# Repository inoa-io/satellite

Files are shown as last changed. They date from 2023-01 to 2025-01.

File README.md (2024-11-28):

# Inoa Satellite



The Inoa Satellite is a lightweight and secure gateway for your fuse box or industrial environment.

Please see our [Project Pages](https://inoa-io.github.io/satellite/) for details.

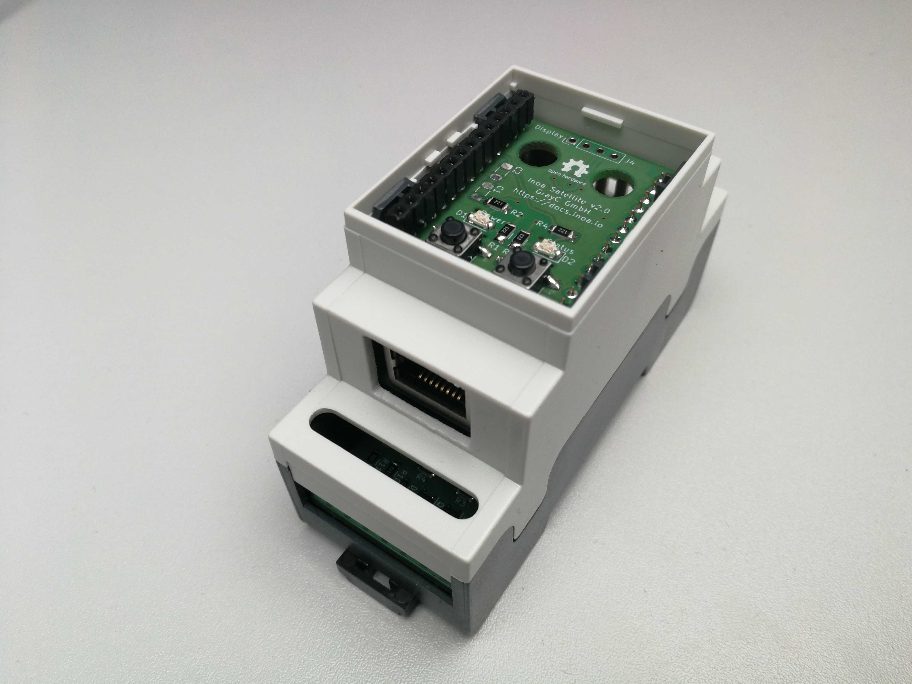
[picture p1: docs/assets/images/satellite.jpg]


## Why?

There is a huge amount of IoT gateways out there, but none of these fulfill completely all of our design goals:

* Usage in a rough industrial environment
* Hardware driven security (HSM)
* Inexpensive hardware to be able to finance a huge fleet of devices
* Low energy consumption
* Fuse box casing (DIN rail)
* Small (2 FE / 36 mm) to allow mounting in existing fuse boxes
* Extendable design to be future proof
* Modular design to adapt hardware to use cases and keep costs low

## How?

We use [KiCad](https://www.kicad.org/) for our PCB designs, [Parts Community](https://b2b.partcommunity.com/) and [SnapEDA](https://www.snapeda.com/) for symbols, footprints, models 'n stuff...

To meet our design goals, we decided to:

* Use the ESP32
* Use the ATECC family of chips as HSM
* Choose industrial proof parts, shielding and ESD protection
* Pick a certified DIN rail casing
* Cut the design to several stacked modules

## Modules

### General

The Satellite comes with a stacked design allowing to interchange the modules on each level of the stack to fit the needs of its planned duty.

This allows quick and cheap adjustment of single devices, ensures expandability, keeps costs low and offers replacement of defect modules with spare parts.

The Satellite consists of up to 4 levels (level 1 is the bottom). Level 3 is an optional level and may be left out.

* Level 1 holds the power supply and metering / control peripheries.
* Level 2 is the main module for the micro controller
* Level 3 is the network / communication level (Ethernet, NB IoT, LoRa, ...)
* Level 4 is meant for the user panel

### Metering Modules

#### Electric Metering Module

The electric metering module is dedicated to be used for interacting with electric meters, inverters, batteries and so on. It is a base module on level 1 of the stack. Its features are:

* 5V-24V power input
* PE / Shield pin
* 2x RS485 interface (used for e.g. ModBus, ...)
* 2x pulse interface (S0, Photoelectric barrier, ...)
* 2x relay driver

#### CT Metering Module

The CT module is dedicated to be used for EMS use cases. Current transformers (split core) with voltage output may be used (e.g. SCT-013).

It is a base module on level 1 of the stack. Its features are:

* 5V-24V power input
* 3x CT
* 1x Analog in (ADC)
* 1x Digital in (e.g. S0 meters)
* 1x RS485 interface (ModBus RTU meters)

#### MBus / WMBus Metering Module

The M-Bus module is dedicated to be used for interacting with different meters via RS485 or M-Bus. The module acts as M-Bus master, but a separate power supply is needed. Because the size of this power supply depends on the amount of connected meters, we decided to give the ability to choose a fitting, external power supply.

The M-Bus module is a base module on level 1 of the stack. Its features are:

* 5V-24V power input
* 1x M-Bus interface
* 1x RS485 interface (ModBus RTU meters)
* 2x pulse interface (S0 meters)
* PE / Shield pins for bus connections

### SoC Module

The SoC module is the heart of the satellite and home of the microprocessor, flash memory and HSM (hardware security module). It is the main module on level 2 of the stack. Its features are:

* ESP32 MPU (32 Bit, Dual Core, 240 MHz)
* 8 MB RAM
* 16 MB flash
* µSD Card slot for external storage
* HSM (ATECC608)

### Ethernet Module

The Ethernet module connects the Satellite to Ethernet. It is a network module on level 3 of the stack. Its features are:

* W5500 Ethernet chip (MAC+PHY)
* ESD protection
* Shielded RJ45 plug

### NB IoT Module

_**Coming soon**_

### LoRa Module

_**Coming soon**_

### Panel Module

The panel module is the "user interface" and home of all user input output devices of the Satellite. It is the top module on level 4. Its features are:

* Power and status LED
* Reset and setup button
* 128x64 OLED display (optional)
* RS232 Debug interface
* External WiFi antenna (optional)

## Casings

We use a DIN rail mounted casing in 2 FE width. See [Datasheet](./casing/rail/apra_rail_Leiterkartengroessen_PCB_Dimensions_de_en.pdf) for details.

## Development

### Building the Project

You will need:

* Python >= 3.8
* [KiBot](https://github.com/INTI-CMNB/KiBot) (see [installation instructions](https://github.com/INTI-CMNB/KiBot#installation-on-ubuntu-or-debian))

Clone this project and run `./build.sh`. You will get a selection of the possible modules to be built. Tests will be executed and the build result is placed in the `out` folder.

### Project structure

| Folder | Purpose |
|---|---|
| ./casing | Construction files for the casing |
| ./configs | KiCad-Export configuration |
| ./development-board  | Design for the development board |
| ./docs | Documentation |
| ./ethernet-extension | Design for the Ethernet module |
| ./libraries | Electric symbols, footprints and 3D models |
| ./metering-module | Design for the metering module |
| ./nbiot-extension | Design for the NB IoT module |
| ./out | Build output folder |
| ./panel-module | Design for the panel module |
| ./soc-module | Design for the SoC module |

### Conventions

#### Markings

* Each PCB has an etched label for "TOP" and "BOT" marks
* Each PCB has an etched label for the product serial following the pattern: SR-XX-NNN (e.g. SR-SM-021)
* The product serial start with "SR" for "Satellite Rail", the next two characters are reserved for the module, the 3 digits represents the version

| Serial | Module / Part | Current Version |
|---|---|---|
| SR-SC-XXX | SoC Module | v2.0 |
| SR-EM-XXX | Electric Metering | v2.0 |
| SR-CM-XXX | Current Loop Metering  | v2.0 |
| SR-MM-XXX | MBus / WMBus Metering  | v2.0 |
| SR-ET-XXX | Ethernet Module | v2.0 |
| SR-NB-XXX | NB IoT Module | v2.0 |
| SR-LR-XXX | LoRa / LoRa WAN Module | v2.0 |
| SR-PN-XXX | Panel Module | v2.0 |

#### Tracks / Vias / Grids

Despite of the low energy consumption of the MCU itself, we are planning with a maximum current of 1A to be future proof for extra extensions that have a higher energy demand (LoRa, NB IoT, ...).

We chose two different of track widths for main power and for data lines (0.25 mm / 0.5 mm) and planned a minimum temperature of 0°C. See the table below.

| Track (mm) | Track (mil) | 10°  | 20°  | 30°  | 40°  | 50°  | 60°  |
|---|---|---|---|---|---|---|---|
| 0.1mm | 4mil | 0.4A | 0.6A | 0.8A | 0.9A | 1.0A | 1.1A |
| 0.2mm | 8mil | 0.7A | 1.0A | 1.2A | 1.4A | 1.6A | 1.7A |
| 0.3mm | 12mil | 0.9A | 1.3A | 1.6A | 1.8A | 2.0A | 2.2A |
| 0.4mm | 16mil | 1.1A | 1.5A | 1.9A | 2.2A | 2.4A | 2.7A |
| 0.5mm | 20mil | 1.3A | 1.8A | 2.2A | 2.5A | 2.8A | 3.1A |
| 0.6mm | 24mil | 1.4A | 2.0A | 2.4A | 2.8A | 3.1A | 3.4A |

We chose a 0.1mm grid for all PCB designs, because our casings and mechanics are also measured in millimeters.

We chose 0.8mm 0.4mm vias.

## Pin Out

| Pin ESP | Pin Satellite | Pin Name  | Standard Purpose |
|---|---|---|---|
| 1 | East 1 | GND | Ground |
| 2 | West 1 | 3V3 | Power supply |
| 3 | West 2 | EN3 | Reset |
| 4 | West 3 | I36 | I2C Interrupt |
| 5 | West 4 | I39 | UART 1 RX |
| 6 | West 5 | I34 | SPI 2 MISO |
| 7 | West 6 | I35 | UART 2 RX |
| 8 | West 7 | IO32 | SPI 2 MOSI |
| 9 | West 8 | IO33 | SPI 2 CLK |
| 10 | West 9 | IO25 | UART 1 TXE |
| 11 | West 10 | IO26 | UART 1 TX |
| 12 | West 11 | IO27 | SPI 2 CS (Ethernet)  |
| 13 | West 12 | IO14 | Ethernet Reset |
| 14 | West 13 | IO12 | |
| 15 | NC | GND | Ground |
| 16 | West 14 | IO13 | Status LED |
| 17 | NC | NC | Internal Flash / RAM |
| 18 | NC | NC | Internal Flash / RAM |
| 19 | NC | NC | Internal Flash / RAM |
| 20 | NC | NC | Internal Flash / RAM |
| 21 | NC | NC | Internal Flash / RAM |
| 22 | NC | NC | Internal Flash / RAM |
| 23 | East 13 | IO15 | UART 2 TX |
| 24 | East 12 | IO2 | UART 2 TXE |
| 25 | East 11 | IO0 | Setup Button |
| 26 | East 10 | IO4 | Ethernet Interrupt |
| 27 | NC | NC | Internal Flash / RAM |
| 28 | NC | NC | Internal Flash / RAM |
| 29 | East 9 | IO5 | SPI 1 CS (SD) |
| 30 | East 8 | IO18 | SPI 1 CLK |
| 31 | East 7 | IO19 | SPI 1 MISO |
| 32 | NC | NC | Internal Flash / RAM |
| 33 | East 6 | IO21 | I2C SDA |
| 34 | East 5 | URXD0 | UART 0 RX |
| 35 | East 4 | UTXD0 | UART 0 TX |
| 36 | East 3 | IO22 | I2C SCL |
| 37 | East 2 | IO23 | SPI 1 MOSI |
| 38 | East 1 | GND | Ground |
| NC | East 14 | Shield | Shield / PE |

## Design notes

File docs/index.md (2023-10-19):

# Inoa Satellite Gateway

Satellite Gateway

## General

The Inoa Satellite is a lightweight and secure gateway for your fuse box or industrial environment with a DIN rail mounted casing which is 2 FE wide.

It features an ESP32 MPU with 240MHz dual core, 8MB Ram, 16MB program flash and a SD card slot for SSD usage.

## Design Goals

* Usage in a rough industrial environment
* Hardware driven security (HSM)
* Cheap hardware to be able to finance a huge fleet of devices
* Low energy consumption due to possible battery driven usage
* Fuse box casing (DIN rail)
* Small (2 FE / 36mm) to allow mounting in existing fuse boxes
* Extendable design to be future proof
* Modular design to adapt hardware to use cases and keep costs low

## Modular Design

The Satellite comes with a stacked design allowing to interchange the modules on each level of the stack to fit the needs of its planned duty.

This allows quick and cheap adjustment of single devices, ensures expandability, keeps costs low and offers replacement of defect modules with spare parts.

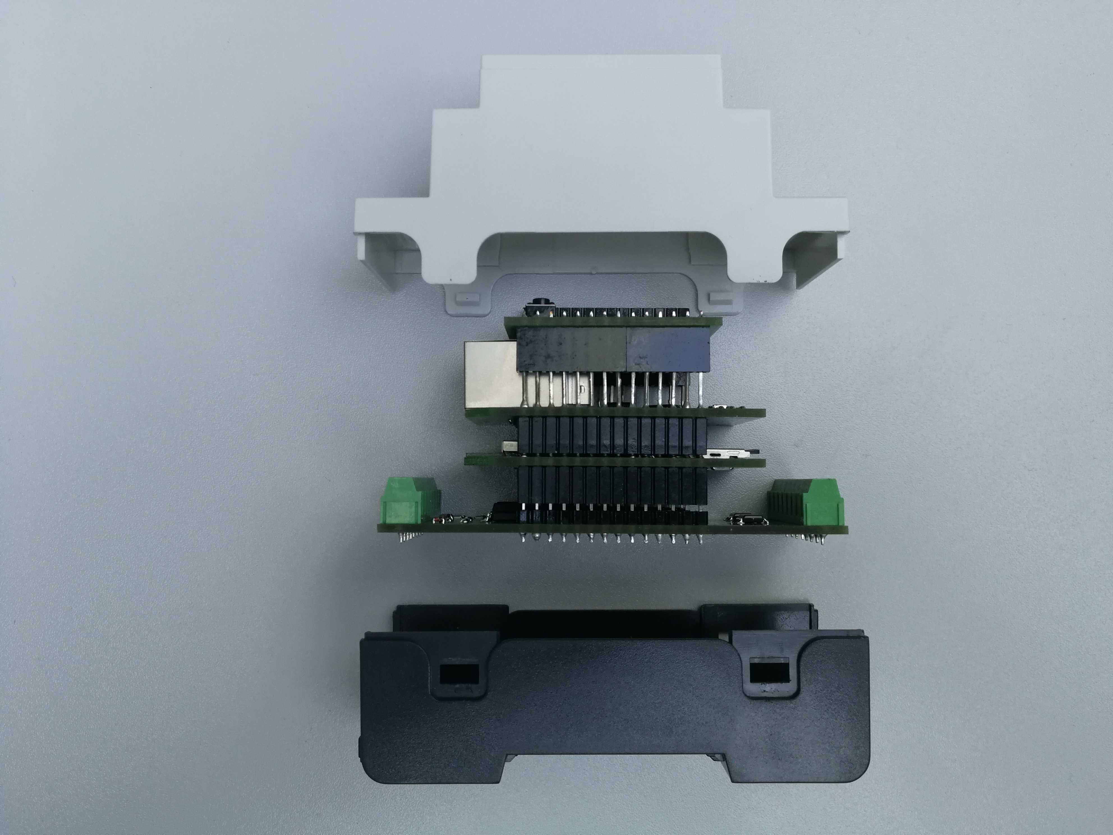
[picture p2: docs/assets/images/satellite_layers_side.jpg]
Satellite Module Layers


The Satellite consists of up to 4 levels (level 1 is the bottom). Level 3 is an optional level and may be left out.

* Level 1 holds the power supply and metering / control peripheries.
* Level 2 is the main module for the micro controller
* Level 3 is the network / communication level (Ethernet, NB IoT, LoRa, ...)
* Level 4 is meant for the user panel or other external I/O interfaces

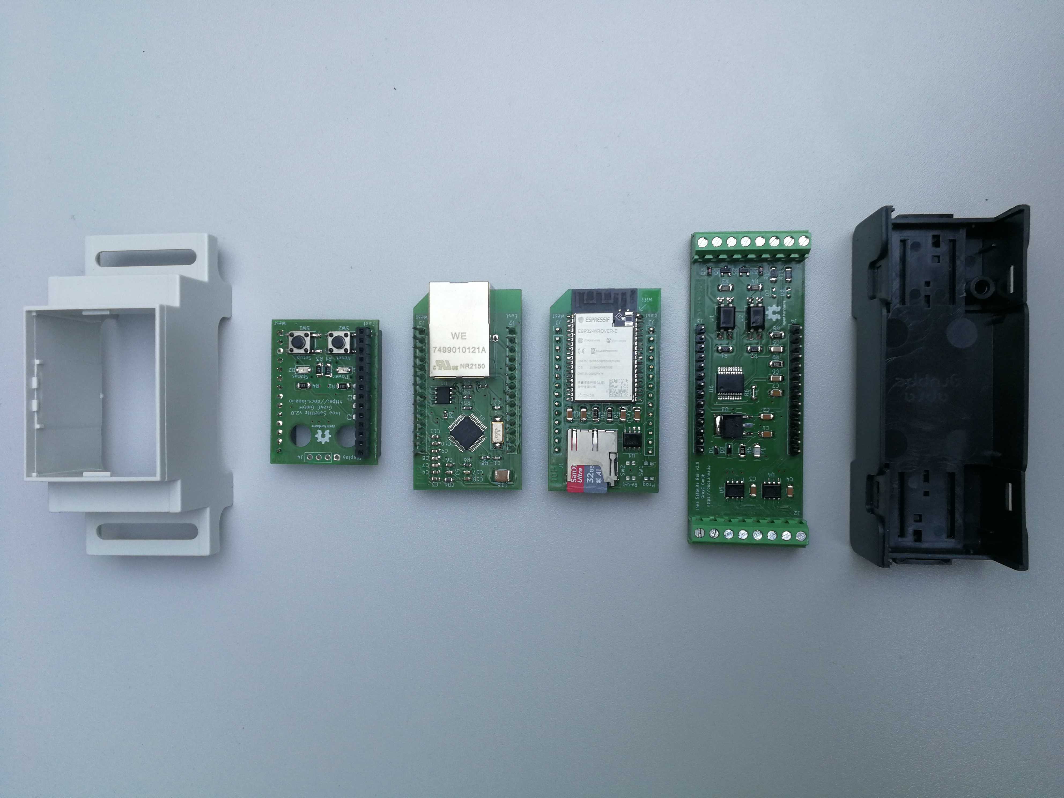
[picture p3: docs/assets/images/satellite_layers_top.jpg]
Satellite Module Layers


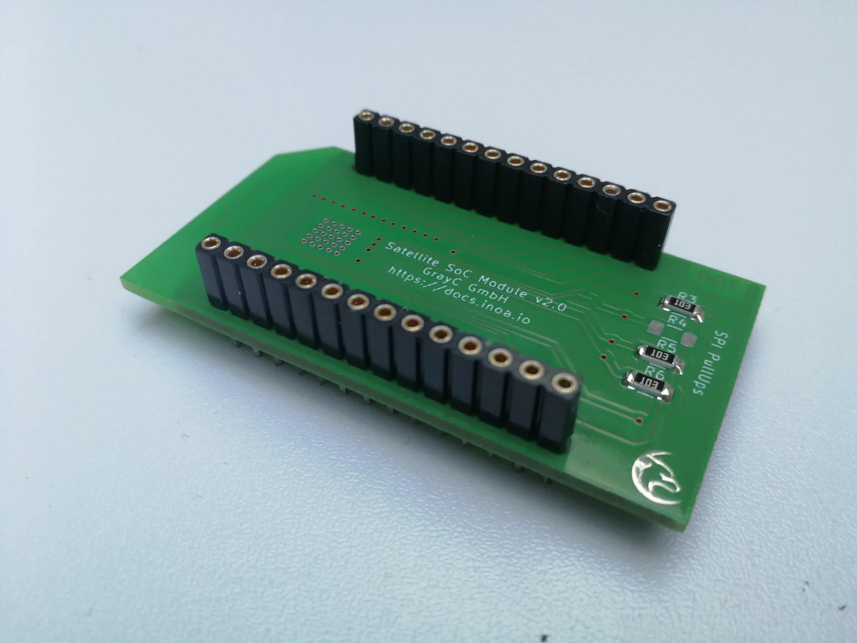
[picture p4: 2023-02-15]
docs/assets/images/satellite_soc_bottom.jpg

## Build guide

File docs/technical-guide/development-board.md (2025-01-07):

# Development Board

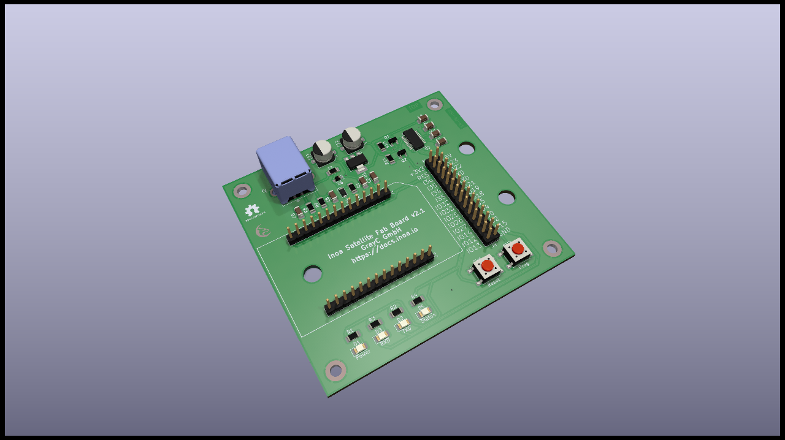
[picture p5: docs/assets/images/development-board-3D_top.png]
Development Board Model


## Specifications

The Development Board is a tool to flash, debug and develop new Satellite modules. Any Satellite module can be connected to the board. Even a whole stack (SoC, networtk and panel module) can be used. The module has an USB connection that will power the connected modules when plugged in. Also, the module has an onboard USB to UART adapter, so the Satellites' debug console can be used directly via USB. The board has an auto programmer circuit, so connected SoC modules can be automatically flashed from the host PC. For further development, there is also a pin header providing the complete system bus.

## Schematics

Development Board Schematics

## Resources

* [PCB Top](../generated/pcb/development-board-F_Cu.svg)
* [PCB Bottom](../generated/pcb/development-board-B_Cu.svg)
* [Bill of material](../generated/bom/development-board-bom.csv)

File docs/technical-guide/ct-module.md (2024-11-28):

# CT Module

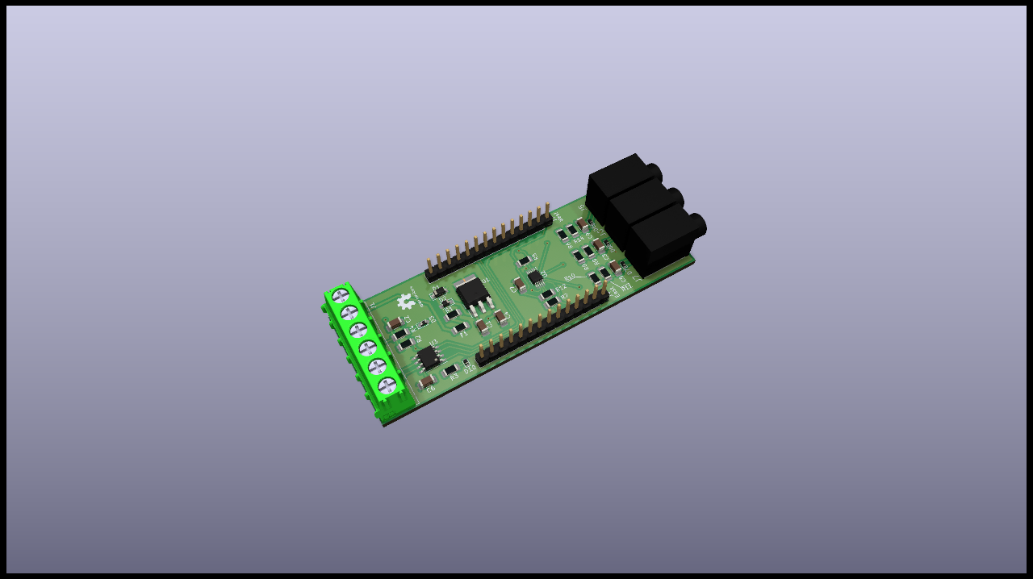
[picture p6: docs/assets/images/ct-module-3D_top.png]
CT Module Model


## Specifications

The CT module is dedicated to be used for EMS use cases. Current transformers (split core) with voltage output may be used (e.g. SCT-013).

It is a base module on level 1 of the stack. Its features are:

* 5V-24V power input
* 3x CT
* 1x Analog in (ADC)
* 1x Digital in (e.g. S0 meters)
* 1x RS485 interface (ModBus RTU meters)

## Schematics

CT Module Schematics

## Resources

* [PCB Top](../generated/pcb/ct-module-F_Cu.svg)
* [PCB Bottom](../generated/pcb/ct-module-B_Cu.svg)
* [Bill of material](../generated/bom/ct-module-bom.csv)

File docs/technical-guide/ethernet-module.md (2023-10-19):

# Ethernet Module

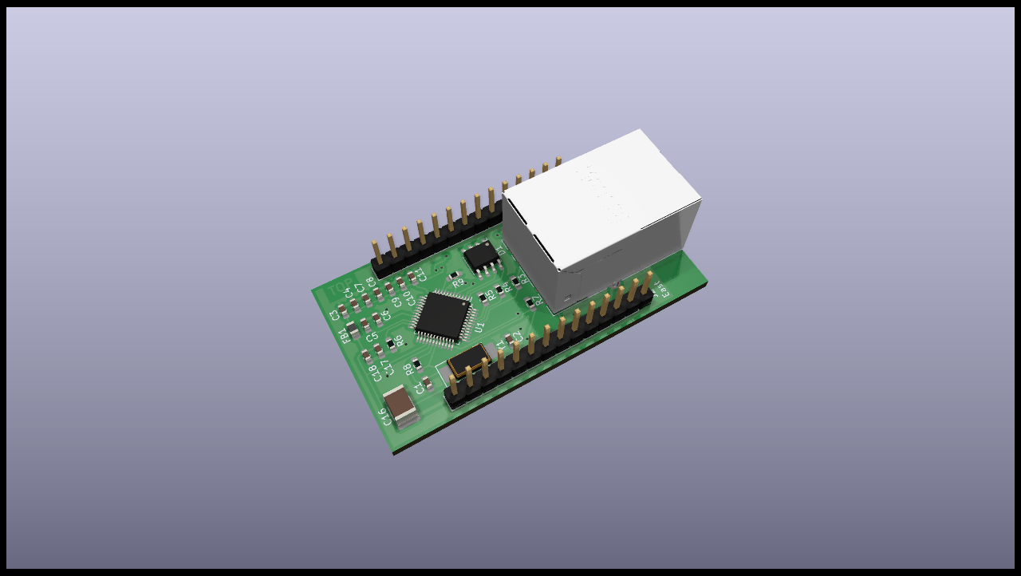
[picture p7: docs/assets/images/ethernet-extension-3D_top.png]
Ethernet Module Model


## Specifications

The Ethernet module connects the Satellite to Ethernet. It is a network module on level 3 of the stack. Its features are:

* W5500 Ethernet chip (MAC+PHY)
* ESD protection
* Shielded RJ45 plug

## Schematics

Ethernet Module Schematics

## Resources

* [PCB Top](../generated/pcb/ethernet-extension-F_Cu.svg)
* [PCB Bottom](../generated/pcb/ethernet-extension-B_Cu.svg)
* [Bill of material](../generated/bom/ethernet-extension-bom.csv)

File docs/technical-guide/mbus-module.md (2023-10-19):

# M-Bus Module

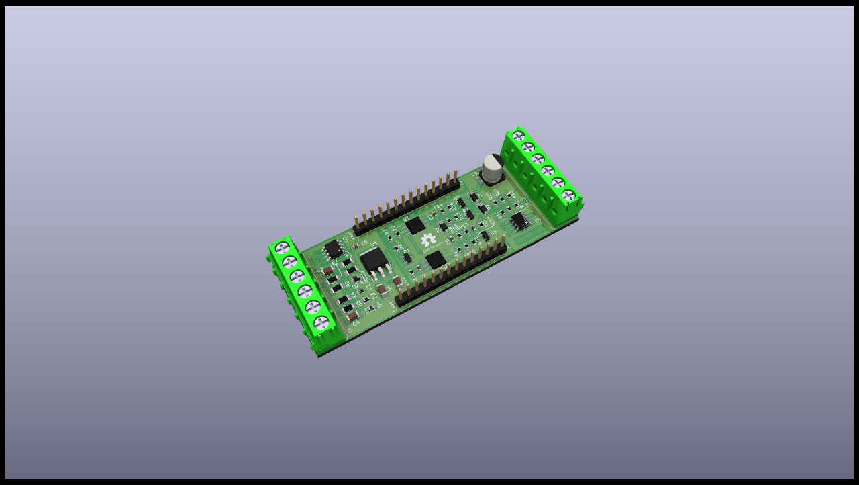
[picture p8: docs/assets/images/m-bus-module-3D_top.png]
M-Bus Module Model


## Specifications

The M-Bus module is dedicated to be used for interacting with different meters via RS485 or M-Bus. The module acts as M-Bus master, but a separate power supply is needed. Because the size of this power supply depends on the amount of connected meters, we decided to give the ability to choose a fitting, external power supply.

The M-Bus module is a base module on level 1 of the stack. Its features are:

* 5V-24V power input
* 1x M-Bus interface
* 1x RS485 interface (ModBus RTU meters)
* 2x pulse interface (S0 meters)
* PE / Shield pins for bus connections

## Schematics

M-Bus Module Schematics

## Resources

* [PCB Top](../generated/pcb/m-bus-module-F_Cu.svg)
* [PCB Bottom](../generated/pcb/m-bus-module-B_Cu.svg)
* [Bill of material](../generated/bom/m-bus-module-bom.csv)

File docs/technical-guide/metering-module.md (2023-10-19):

# Electric Metering Module

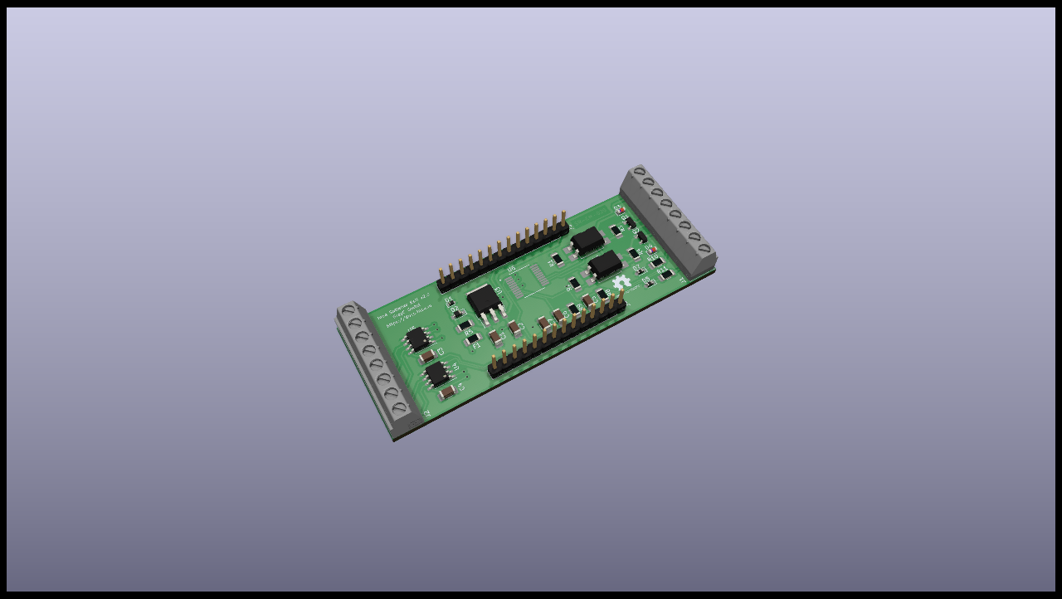
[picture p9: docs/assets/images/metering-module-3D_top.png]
Electric Metering Module Model


## Specifications

The electric metering module is dedicated to be used for interacting with electric meters, inverters, batteries and so on. It is a base module on level 1 of the stack. Its features are:

* 5V-24V power input
* PE / Shield pin
* 2x RS485 interface (used for e.g. ModBus, ...)
* 2x pulse interface (S0, Photoelectric barrier, ...)
* 2x relay driver

## Schematics

Electric Metering Module Schematics

## Resources

* [PCB Top](../generated/pcb/metering-module-F_Cu.svg)
* [PCB Bottom](../generated/pcb/metering-module-B_Cu.svg)
* [Bill of material](../generated/bom/metering-module-bom.csv)

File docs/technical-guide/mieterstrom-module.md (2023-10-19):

# Mieterstrom Module

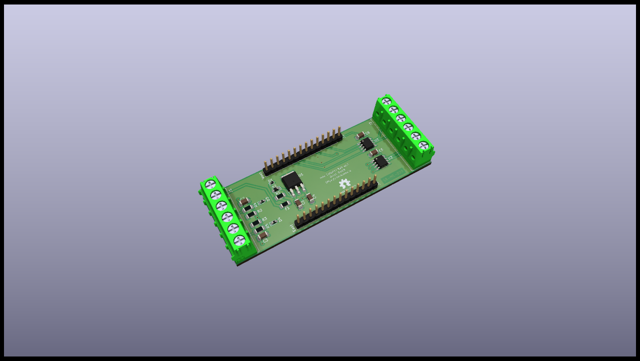
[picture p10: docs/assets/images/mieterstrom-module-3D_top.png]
Mieterstrom Module Model


## Specifications

The Mieterstrom module is dedicated to be used for interacting with electric meters in a tenement environment. In this case, there are different types of meters used and so a need of different bus speeds may needed.

It is a base module on level 1 of the stack. Its features are:

* 5V-24V power input
* 2x RS485 interface (ModBus RTU meters)
* 2x pulse interface (S0 meters)
* PE / Shield pins for bus connections

## Schematics

Mieterstrom Module Schematics

## Resources

* [PCB Top](../generated/pcb/mieterstrom-module-F_Cu.svg)
* [PCB Bottom](../generated/pcb/mieterstrom-module-B_Cu.svg)
* [Bill of material](../generated/bom/mieterstrom-module-bom.csv)

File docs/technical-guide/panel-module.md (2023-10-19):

# Panel Module

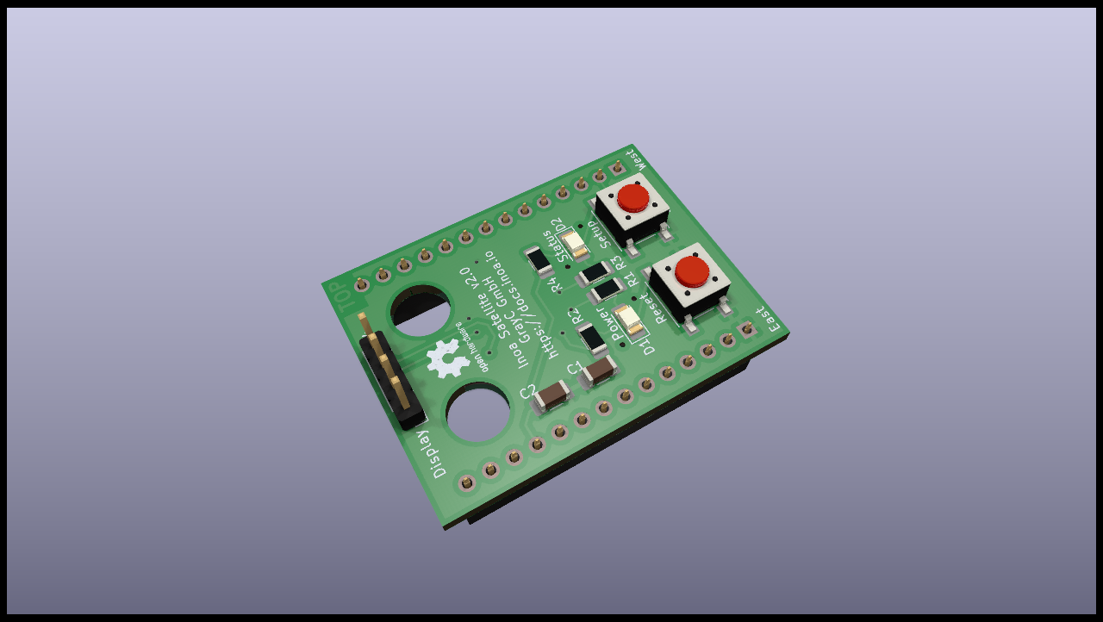
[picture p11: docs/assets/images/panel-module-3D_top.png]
Panel Module Model


## Specifications

The panel module is the "User Interface" and home of all user input output devices of the Satellite. It is the top module on level 4. Its features are:

* Power and status LED
* Reset and setup button
* 128x64 OLED display (optional)
* RS232 Debug interface
* External WiFi antenna (optional)

## Schematics

Panel Module Schematics

## Resources

* [PCB Top](../generated/pcb/panel-module-F_Cu.svg)
* [PCB Bottom](../generated/pcb/panel-module-B_Cu.svg)
* [Bill of material](../generated/bom/panel-module-bom.csv)

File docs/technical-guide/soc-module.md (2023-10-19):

# SoC Module

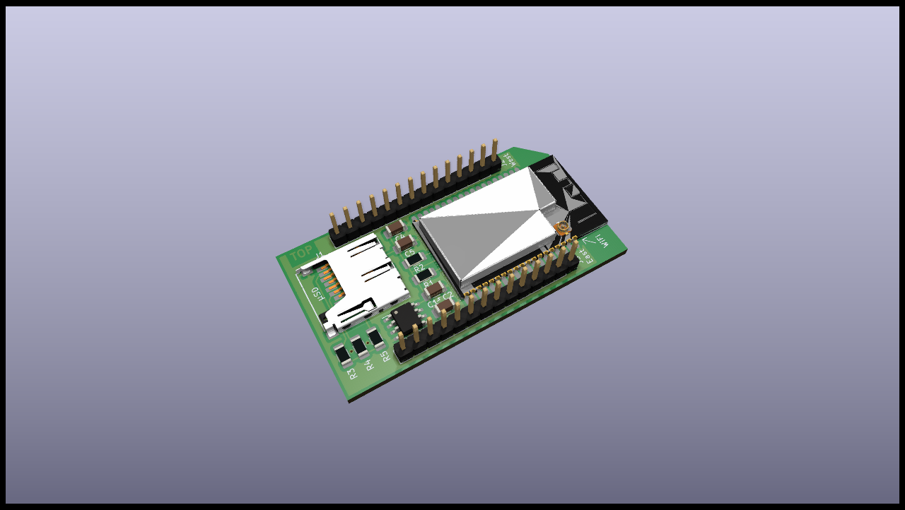
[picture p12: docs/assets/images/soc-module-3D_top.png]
Test


## Specifications

The SoC module is the heart of the Satellite and home of the microprocessor, flash memory and HSM (hardware security module). It is the main module on level 2 of the stack. Its features are:

* ESP32 MPU (32 Bit, Dual Core, 240 MHz)
* 8 MB RAM
* 16 MB flash
* µSD Card slot for external storage
* HSM (ATECC608)
* RTC (DS3231)

## Schematics

SoC Module Schematics

## Resources

* [PCB Top](../generated/pcb/soc-module-F_Cu.svg)
* [PCB Bottom](../generated/pcb/soc-module-B_Cu.svg)
* [Bill of material](../generated/bom/soc-module-bom.csv)

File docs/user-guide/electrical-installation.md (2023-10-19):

# Electrical Installation

The electrical installation may differ based on the metering module of the satellite. Some modules might have other pin connection based on the provided interfaces (e.g. ModBus, CAN, KNX, ...).

Please find the installation instructions for your specific model below.

## General

All Satellite "Rail" models are meant to be mounted on a DIN rail at indoor sites. For outdoor usage please refer to the Satellite "Probe" models.

All models uses internal micro SD cards as file storage. You can insert an SD card of your choice by opening the case popping the 4 latches out with a screw driver. The card can be inserted at the upper side of the PCB "sandwich".

## Tenant Electricity Model

The metering model is able to connect to 2 different RS485 buses (e.g. ModBus) running on different baud rates. It is also fitted with 2 digital inputs (e.g. S0).

Please find to pin out below:

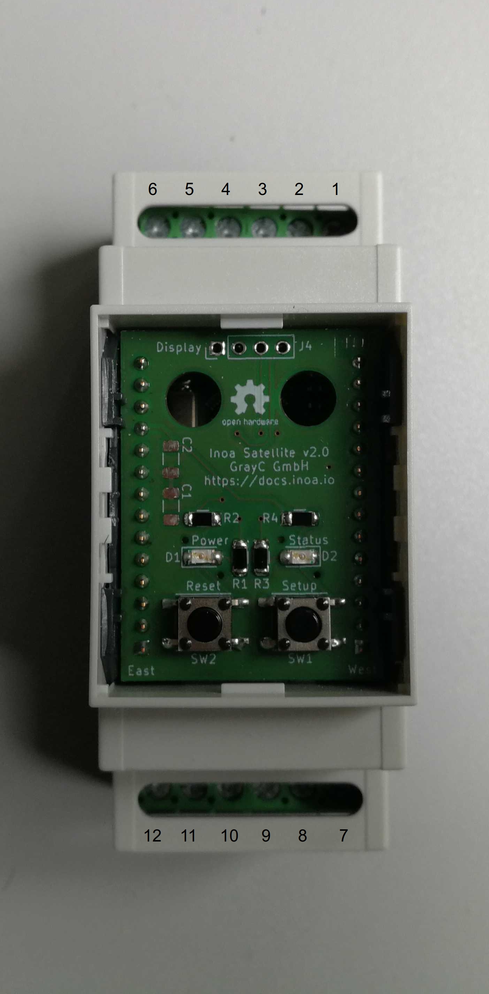
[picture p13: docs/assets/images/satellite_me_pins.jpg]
Satellite Gateway Pins


| Pin | Purpose | Description |
|-----|---|---|
| 1 | +5-24V | Power supply positive 5 to 24 volts, >=3W |
| 2 | Ground | Power supply ground |
| 3 | S0 1 + | S0 interface |
| 4 | S0 1 - | S0 interface |
| 5 | S0 2 + | S0 interface |
| 6 | S0 2 - | S0 interface |
| 7 | RS485 1-B | RS485 1 "B" line |
| 8 | RS485 1-A | RS485 1 "A" line |
| 9 | RS485 1-GND | RS485 1 Ground line (shield) |
| 10  | RS485 2-B | RS485 2 "B" line |
| 11  | RS485 2-A | RS485 2 "A" line |
| 12  | RS485 2-GND | RS485 2 Ground line (shield) |

Connect Pin 1 and 2 to a power supply delivering 5 to 24 volts. Be aware that the best efficiency is achieved with 5 volts. Higher voltages will lead to higher thermal loss. The power supply must be rated for at least 3W.

Connect the RS485 pins as described in the table. Be sure to connect the shield of the RS485 buses to ground pin to avoid stability problems. The Satellite does **not** have internal termination resistors!

The S0 pins should be connected to a S0 device, reed contact, incremental wind sensor, and any other device that uses a simple switch inside.

## M-Bus Model

The M-Bus model is able to connect to a RS485 bus (e.g. ModBus) and also acts as M-Bus master. It is also fitted with 2 digital inputs (e.g. S0).

Please find to pin out below:

Satellite Gateway Pins

| Pin | Purpose | Description |
|-----|---|---|
| 1 | +5-24V | Power supply positive 5 to 24 volts, >=3W |
| 2 | Ground | Power supply ground |
| 3 | S0 1 + | S0 interface |
| 4 | S0 1 - | S0 interface |
| 5 | S0 2 + | S0 interface |
| 6 | S0 2 - | S0 interface |
| 7 | RS485 1-B | RS485 1 "B" line |
| 8 | RS485 1-A | RS485 1 "A" line |
| 9 | M-Bus M- | M-Bus negative bus line |
| 10  | M-Bus M+ | M-Bus positive bus line |
| 11  | M-Bus DC- | M-Bus power supply 9-30V (-) |
| 12  | M-Bus DC+ | M-Bus power supply 9-30V (+) |

Connect Pin 1 and 2 to a power supply delivering 5 to 24 volts. Be aware that the best efficiency is achieved with 5 volts. Higher voltages will lead to higher thermal loss. The power supply must be rated for at least 3W.

Connect the RS485 pins as described in the table. Be sure to connect the shield of the RS485 bus to ground pin to avoid stability problems. The Satellite does **not** have internal termination resistors!

The S0 pins should be connected to a S0 device, reed contact, incremental wind sensor, and any other device that uses a simple switch inside.

Pin 9 and 10 acts as M-Bus data line. Connect the M-Bus power supply to pin 11 and 12. Be sure to use the correct polarity! The power supply drives the M-Bus, so choose a fitting one depending on the number of connected meters.

## Electric Metering Model

The metering model is able to connect to 2 different RS485 buses (e.g. ModBus) running on different baud rates. It is also able to drive 2 relays and to connect to 2 digital inputs (e.g. S0).

Please find to pin out below:

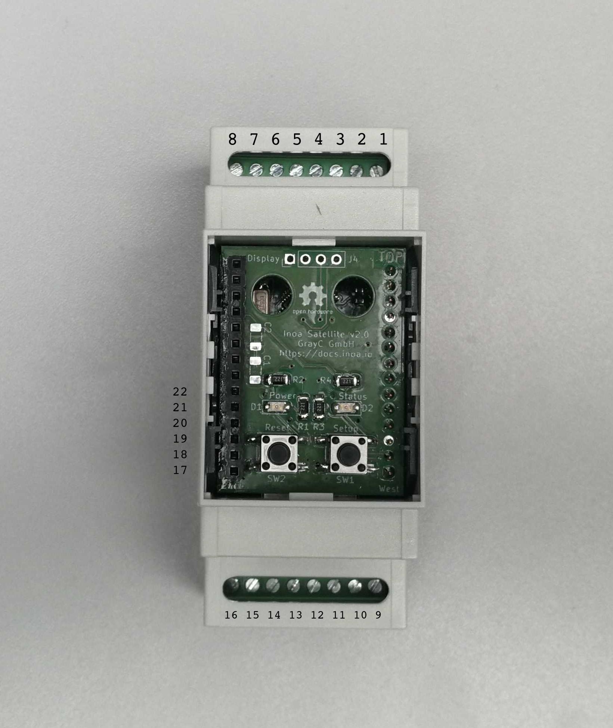
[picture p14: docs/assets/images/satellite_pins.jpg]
Satellite Gateway Pins


| Pin | Purpose | Description |
|-----|---|---|
| 1 | +5-24V | Power supply positive 5 to 24 volts |
| 2 | Ground | Power supply ground |
| 3 | Shield | Connect to earth |
| 4 | shield | Connect to earth |
| 5 | RS485 1-A | RS485 "A" line |
| 6 | RS485 1-B | RS485 "B" line |
| 7 | RS485 2-A | RS485 "A" line |
| 8 | RS485 2-B | RS485 "B" line |
| 9 | Relay Power + | Power supply for relays positive (e.g. 12 or 24 volts) |
| 10  | Relay Power - | Power supply for relays ground |
| 11  | Relay 1 | Relay switch (will become negative if switched) |
| 12  | Relay 2 | Relay switch (will become negative if switched) |
| 13  | S0 1 + | S0 interface |
| 14  | S0 1 - | S0 interface |
| 15  | S0 2 + | S0 interface |
| 16  | S0 2 - | S0 interface |
| 17  | Ground | Power supply ground |
| 18  | Do not use | Do not use (future use for internal SD) |
| 19  | I²C SCL | External I²C |
| 20  | Debug UART TX | Debug console |
| 21  | Debug UART RX | Debug console |
| 22  | I²C SDA | External I²C |
| >22 | Do not use | Do not use (future use for internal SD) |

Connect Pin 1 and 2 to a power supply delivering 5 to 24 volts. Be aware that the best efficiency is achieved with 5 volts. Higher voltages will lead to higher thermal loss. The power supply must be rated for at least 3W.

Connect the RS485 pins as described in the table. Be sure to connect the shield of the RS485 bus to pin 3 or 4 to avoid stability problems. The Satellite does **not** have internal termination resistors!

The S0 pins should be connected to a S0 device, reed contact, incremental wind sensor, and any other device that uses a simple switch inside.

The relay power contacts have to be connected to an external power source. You might use the same power supply as used for the Satellite itself - depending on the voltage ratings of the used relay. Connect one positive wire of the power supply to your relay positive input. The negative input of the relay is connected to one of the switch pins 11 or 12.

## Debug console

All Satellite models can be debugged using an USB to UART adapter like the FT232. Connect the adapter to your PC. Connect the TX line to pin 20 and the RX line to pin 21. You also have to connect the ground line to pin 17.

Use a terminal tool of your choice, e.g. [GTKTerm](https://github.com/Jeija/gtkterm). Set the baud rate to 115200 and the bit configuration to 8N1.

Please refer to the developer guide for further information about dealing with the debug console!

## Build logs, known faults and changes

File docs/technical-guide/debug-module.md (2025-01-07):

# Debug Module

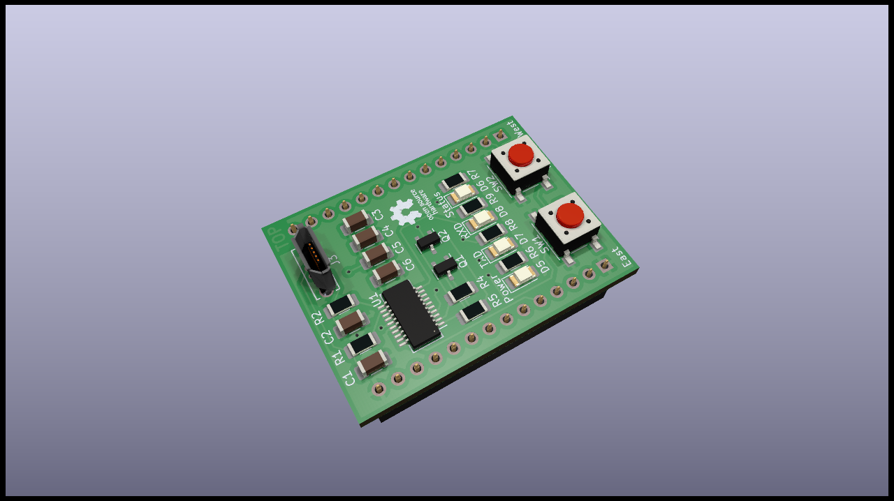
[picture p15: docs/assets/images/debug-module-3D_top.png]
Debug Module Model


## Specifications

The Debug module is a tool to debug Satellites at its installation place. The panel module is removed and the debug module is put at its place instead. The module has an USB connection that will power the Satellite when plugged in. Also, the module has an onboard USB to UART adapter, so the Satellites' debug console can be used directly via USB.

## Schematics

Debug Module Schematics

## Resources

* [PCB Top](../generated/pcb/debug-module-F_Cu.svg)
* [PCB Bottom](../generated/pcb/debug-module-B_Cu.svg)
* [Bill of material](../generated/bom/debug-module-bom.csv)

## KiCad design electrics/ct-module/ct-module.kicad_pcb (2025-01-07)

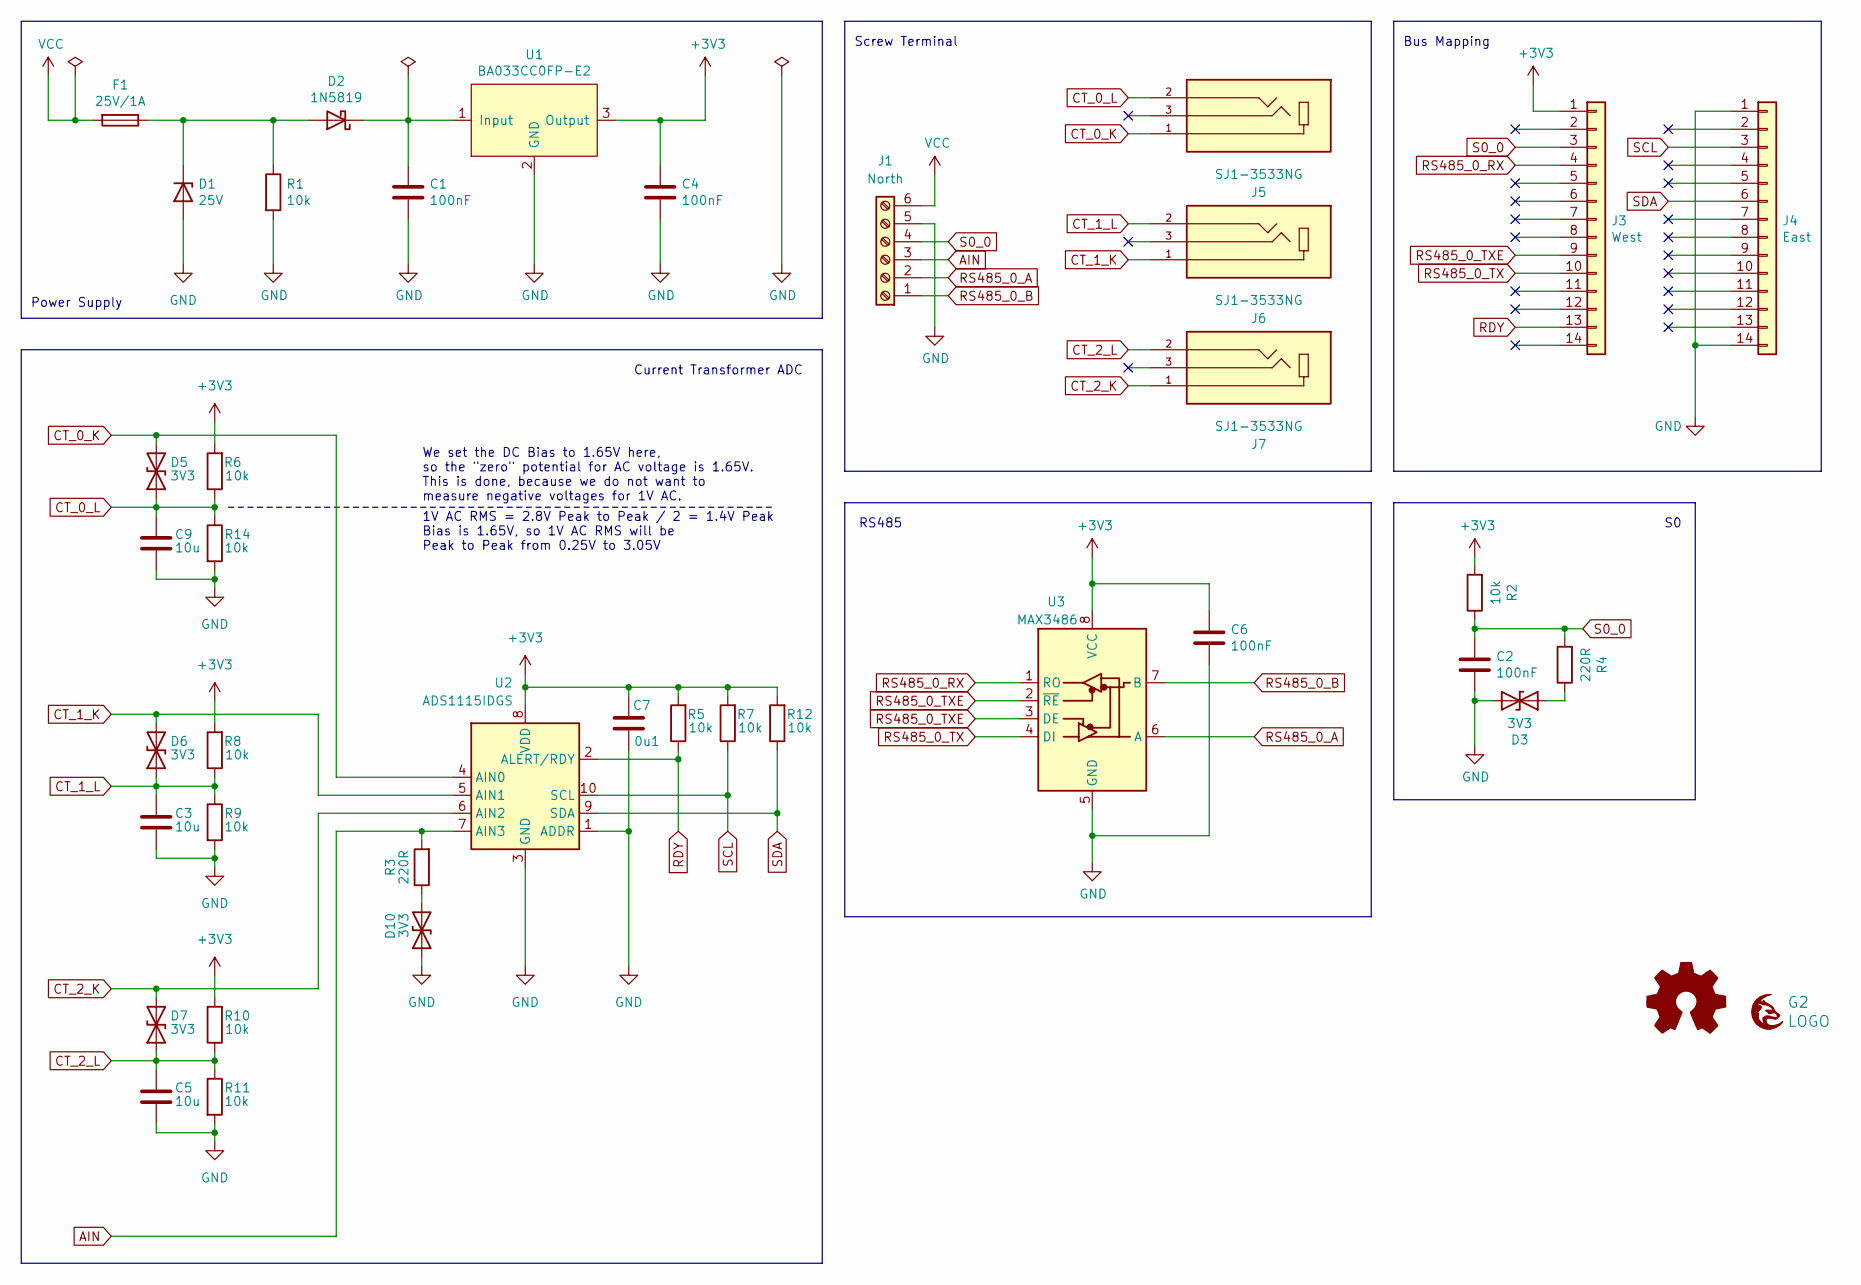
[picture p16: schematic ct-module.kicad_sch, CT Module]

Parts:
C1, C2, C4, C6: 100nF; C_1206_3216Metric_Pad1.33x1.80mm_HandSolder; mouser# 80-C1206C104M5R
C3, C5, C9: 10u; C_1206_3216Metric_Pad1.33x1.80mm_HandSolder; mouser# 80-C1206C106M9R
C7: 0u1; C_1206_3216Metric_Pad1.33x1.80mm_HandSolder; mouser# 80-C1206C104M5R
D1: 25V; D_SOD-123; mouser# 78-MMSZ5253C-E3-08
D2: 1N5819; D_SOD-323_HandSoldering; mouser# 771-PMEG4010CEAX
D3, D5, D6, D7, D10: 3V3; D_0603_1608Metric_Pad1.05x0.95mm_HandSolder; mouser# 652-CG0603MLC-3.3LE
F1: 25V/1A; Fuse_1206_3216Metric_Pad1.42x1.75mm_HandSolder; mouser# 504-TR/3216FF1-R
G1: Logo_Open_Hardware_Small; OSHW-Logo2_7.3x6mm_SilkScreen
G2: LOGO; grayc-logo-negative
J1: North; PHOENIX_1935200; mouser# 651-1935200
J3: West; PinHeader_1x14_P2.54mm_Vertical; mouser# 855-M20-9991446
J4: East; PinHeader_1x14_P2.54mm_Vertical; mouser# 855-M20-9991446
J5, J6, J7: SJ1-3533NG; CUI_SJ1-3533NG; mouser# 490-SJ1-3533NG
R1, R2, R5, R6, R7, R8, R9, R10, R11, R12, R14: 10k; R_1206_3216Metric_Pad1.30x1.75mm_HandSolder; mouser# 652-CR1206JW-103ELF
R3, R4: 220R; R_1206_3216Metric_Pad1.30x1.75mm_HandSolder; mouser# 652-CR0603FX-2200ELF
U1: BA033CC0FP-E2; TO-252-3_TabPin2; mouser# 755-BA033CC0FP-E2
U2: ADS1115IDGS; VSSOP-10_3x3mm_P0.5mm
U3: MAX3486; SOIC-8_3.9x4.9mm_P1.27mm; mouser# 700-MAX3486EESA

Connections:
+3V3: C4.1, C6.1, C7.2, J3.1, R2.2, R5.2, R6.2, R7.2, R8.2, R10.2, R12.2, U1.3 (Output), U2.8 (VDD), U3.8 (VCC)
AIN: J1.3, R3.2, U2.7 (AIN3)
CT_0_K: D5.2 (A2), J5.1, U2.4 (AIN0)
CT_0_L: C9.1, D5.1 (A1), J5.2, R6.1, R14.1
CT_1_K: D6.2 (A2), J6.1, U2.5 (AIN1)
CT_1_L: C3.1, D6.1 (A1), J6.2, R8.1, R9.1
CT_2_K: D7.2 (A2), J7.1, U2.6 (AIN2)
CT_2_L: C5.1, D7.1 (A1), J7.2, R10.1, R11.1
GND: C1.2, C2.2, C3.2, C4.2, C5.2, C6.2, C7.1, C9.2, D1.2 (A), D3.2 (A2), D10.1 (A1), J1.5, J4.1, J4.14, R1.2, R9.2, R11.2, R14.2, U1.2 (GND), U2.1 (ADDR), U2.3 (GND), U3.5 (GND)
unnamed: C1.1, D2.1 (K), U1.1 (Input)
unnamed: D1.1 (K), D2.2 (A), F1.1, R1.1
unnamed: D3.1 (A1), R4.1
unnamed: D10.2 (A2), R3.1
RDY: J3.13, R5.1, U2.2 (ALERT/RDY)
RS485_0_A: J1.2, U3.6 (A)
RS485_0_B: J1.1, U3.7 (B)
RS485_0_RX: J3.4, U3.1 (RO)
RS485_0_TX: J3.10, U3.4 (DI)
RS485_0_TXE: J3.9, U3.2 (~RE), U3.3 (DE)
S0_0: C2.1, J1.4, J3.3, R2.1, R4.2
SCL: J4.3, R7.1, U2.10 (SCL)
SDA: J4.6, R12.1, U2.9 (SDA)
VCC: F1.2, J1.6

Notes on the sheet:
Bus Mapping
1V AC RMS = 2.8V Peak to Peak / 2 = 1.4V Peak Bias is 1.65V, so 1V AC RMS will be Peak to Peak from 0.25V to 3.05V
We set the DC Bias to 1.65V here, so the "zero" potential for AC voltage is 1.65V. This is done, because we do not want to measure negative voltages for 1V AC.
Current Transformer ADC
RS485
Power Supply
Screw Terminal

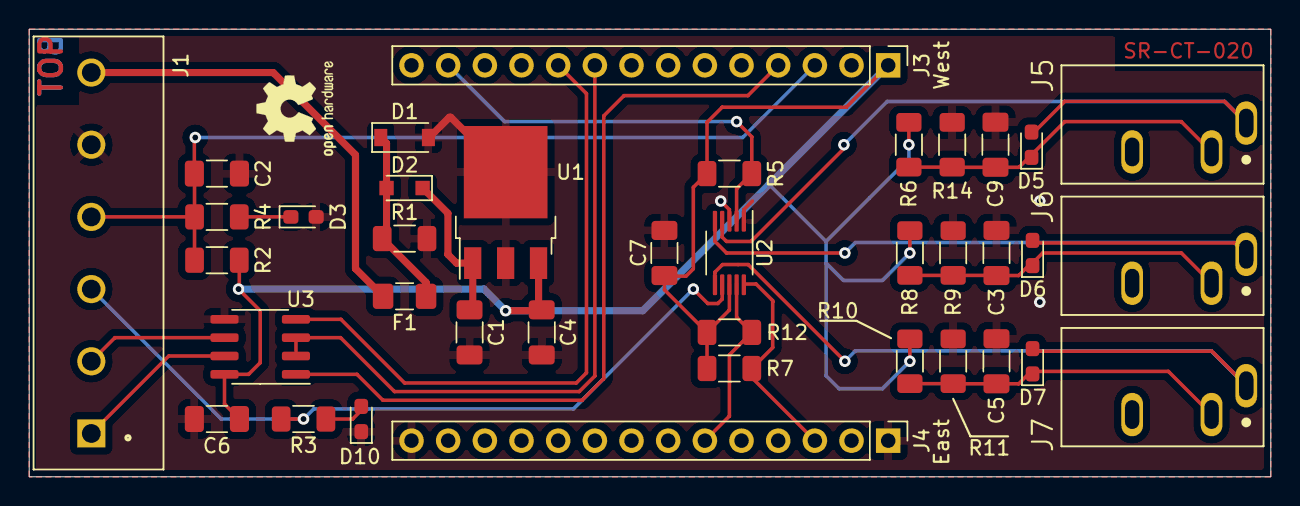
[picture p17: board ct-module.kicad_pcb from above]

Board: 2 copper layers, 86.0 x 31.0 mm, 40 parts (1 on the bottom side), 23 nets.

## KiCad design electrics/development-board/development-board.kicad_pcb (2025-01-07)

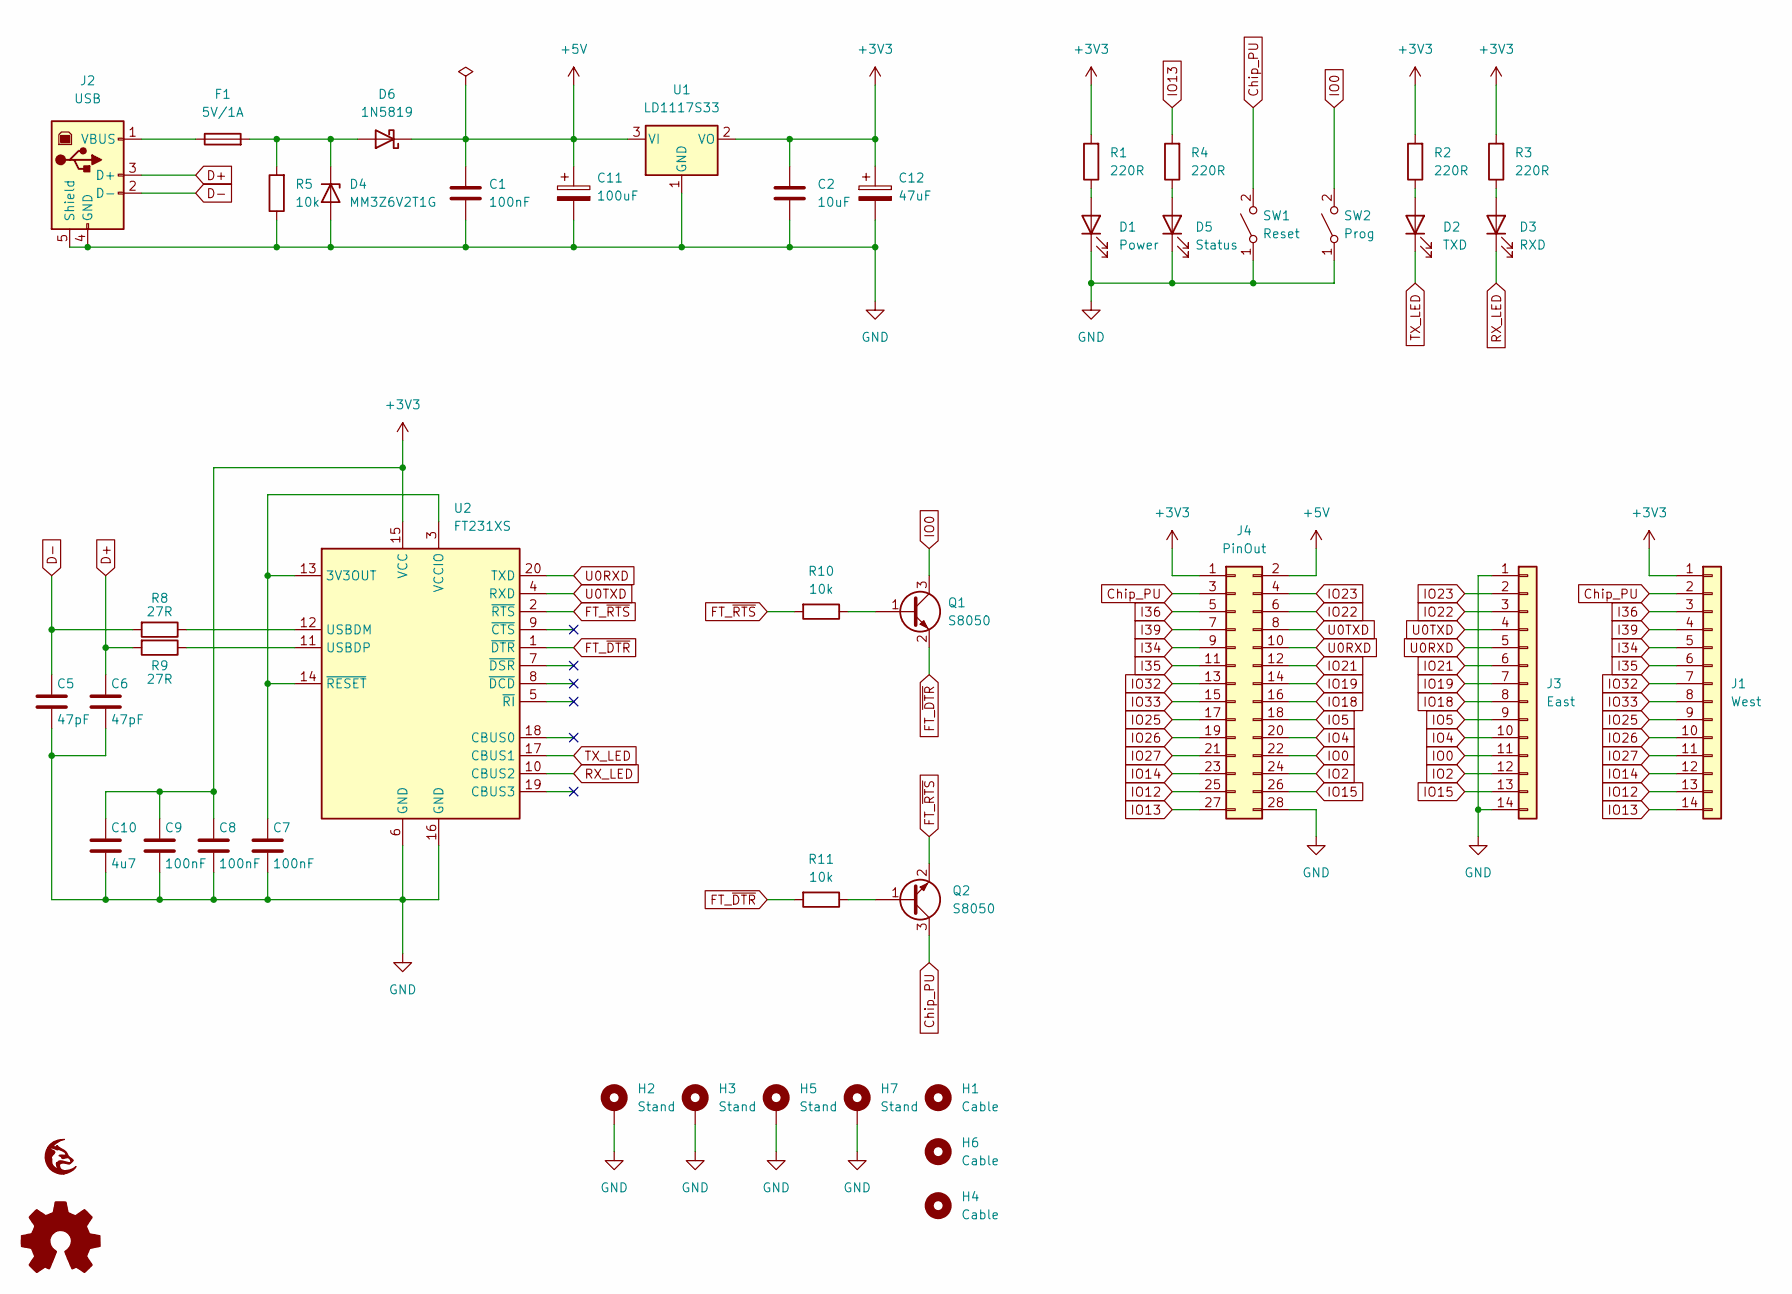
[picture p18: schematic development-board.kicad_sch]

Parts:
C1, C7, C8, C9: 100nF; C_1206_3216Metric_Pad1.33x1.80mm_HandSolder
C2: 10uF; C_1206_3216Metric_Pad1.33x1.80mm_HandSolder
C5, C6: 47pF; C_1206_3216Metric_Pad1.33x1.80mm_HandSolder
C10: 4u7; C_1206_3216Metric_Pad1.33x1.80mm_HandSolder
C11: 100uF; CP_Elec_6.3x5.4
C12: 47uF; CP_Elec_6.3x5.4
D1: Power; LED_1206_3216Metric_Pad1.42x1.75mm_HandSolder
D2: TXD; LED_1206_3216Metric_Pad1.42x1.75mm_HandSolder
D3: RXD; LED_1206_3216Metric_Pad1.42x1.75mm_HandSolder
D4: MM3Z6V2T1G; D_SOD-123F
D5: Status; LED_1206_3216Metric_Pad1.42x1.75mm_HandSolder
D6: 1N5819; D_SOD-323_HandSoldering
F1: 5V/1A; Fuse_1206_3216Metric_Pad1.42x1.75mm_HandSolder
G1: LOGO; grayc-logo-negative
H1, H4, H6: Cable; MountingHole_5.5mm
H2, H3, H5, H7: Stand; MountingHole_3.2mm_M3_DIN965_Pad
J1: West; PinHeader_1x14_P2.54mm_Vertical
J2: USB; USB_B_OST_USB-B1HSxx_Horizontal
J3: East; PinHeader_1x14_P2.54mm_Vertical
J4: PinOut; PinHeader_2x14_P2.54mm_Vertical
LOGO1: Logo_Open_Hardware_Small; OSHW-Logo2_7.3x6mm_SilkScreen
Q1, Q2: S8050; SOT-23-3
R1, R2, R3, R4: 220R; R_1206_3216Metric_Pad1.30x1.75mm_HandSolder
R5, R10, R11: 10k; R_1206_3216Metric_Pad1.30x1.75mm_HandSolder
R8, R9: 27R; R_1206_3216Metric_Pad1.30x1.75mm_HandSolder
SW1: Reset; SW_SPST_PTS645
SW2: Prog; SW_SPST_PTS645
U1: LD1117S33; SOT-223-3_TabPin2
U2: FT231XS; SSOP-20_3.9x8.7mm_P0.635mm

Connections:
+3V3: C2.1, C8.1, C9.1, C10.1, C12.1, J1.1, J4.1, R1.2, R2.2, R3.2, U1.2 (VO), U2.15 (VCC)
+5V: C1.1, C11.1, D6.1 (K), J4.2, U1.3 (VI)
Chip_PU: J1.2, J4.3, Q2.3 (C), SW1.2 (B)
D+: C6.1, J2.3 (D+), R9.2
D-: C5.1, J2.2 (D-), R8.2
FT_~DTR: Q1.2 (E), R11.2, U2.1 (~DTR)
FT_~RTS: Q2.2 (E), R10.2, U2.2 (~RTS)
GND: C1.2, C2.2, C5.2, C6.2, C7.2, C8.2, C9.2, C10.2, C11.2, C12.2, D1.1 (K), D4.2 (A), D5.1 (K), H2.1, H3.1, H5.1, H7.1, J2.4 (GND), J2.5 (Shield), J3.1, J3.14, J4.28, R5.1, SW1.1 (A), SW2.1 (A), U1.1 (GND), U2.6 (GND), U2.16 (GND)
I34: J1.5, J4.9
I35: J1.6, J4.11
I36: J1.3, J4.5
I39: J1.4, J4.7
IO0: J3.11, J4.22, Q1.3 (C), SW2.2 (B)
IO2: J3.12, J4.24
IO4: J3.10, J4.20
IO5: J3.9, J4.18
IO12: J1.13, J4.25
IO13: J1.14, J4.27, R4.2
IO14: J1.12, J4.23
IO15: J3.13, J4.26
IO18: J3.8, J4.16
IO19: J3.7, J4.14
IO21: J3.6, J4.12
IO22: J3.3, J4.6
IO23: J3.2, J4.4
IO25: J1.9, J4.17
IO26: J1.10, J4.19
IO27: J1.11, J4.21
IO32: J1.7, J4.13
IO33: J1.8, J4.15
unnamed: C7.1, U2.3 (VCCIO), U2.13 (3V3OUT), U2.14 (~RESET)
unnamed: D1.2 (A), R1.1
unnamed: D2.2 (A), R2.1
unnamed: D3.2 (A), R3.1
unnamed: D4.1 (K), D6.2 (A), F1.2, R5.2
unnamed: D5.2 (A), R4.1
unnamed: F1.1, J2.1 (VBUS)
unnamed: Q1.1 (B), R10.1
unnamed: Q2.1 (B), R11.1
unnamed: R8.1, U2.12 (USBDM)
unnamed: R9.1, U2.11 (USBDP)
RX_LED: D3.1 (K), U2.10 (CBUS2)
TX_LED: D2.1 (K), U2.17 (CBUS1)
U0RXD: J3.5, J4.10, U2.20 (TXD)
U0TXD: J3.4, J4.8, U2.4 (RXD)

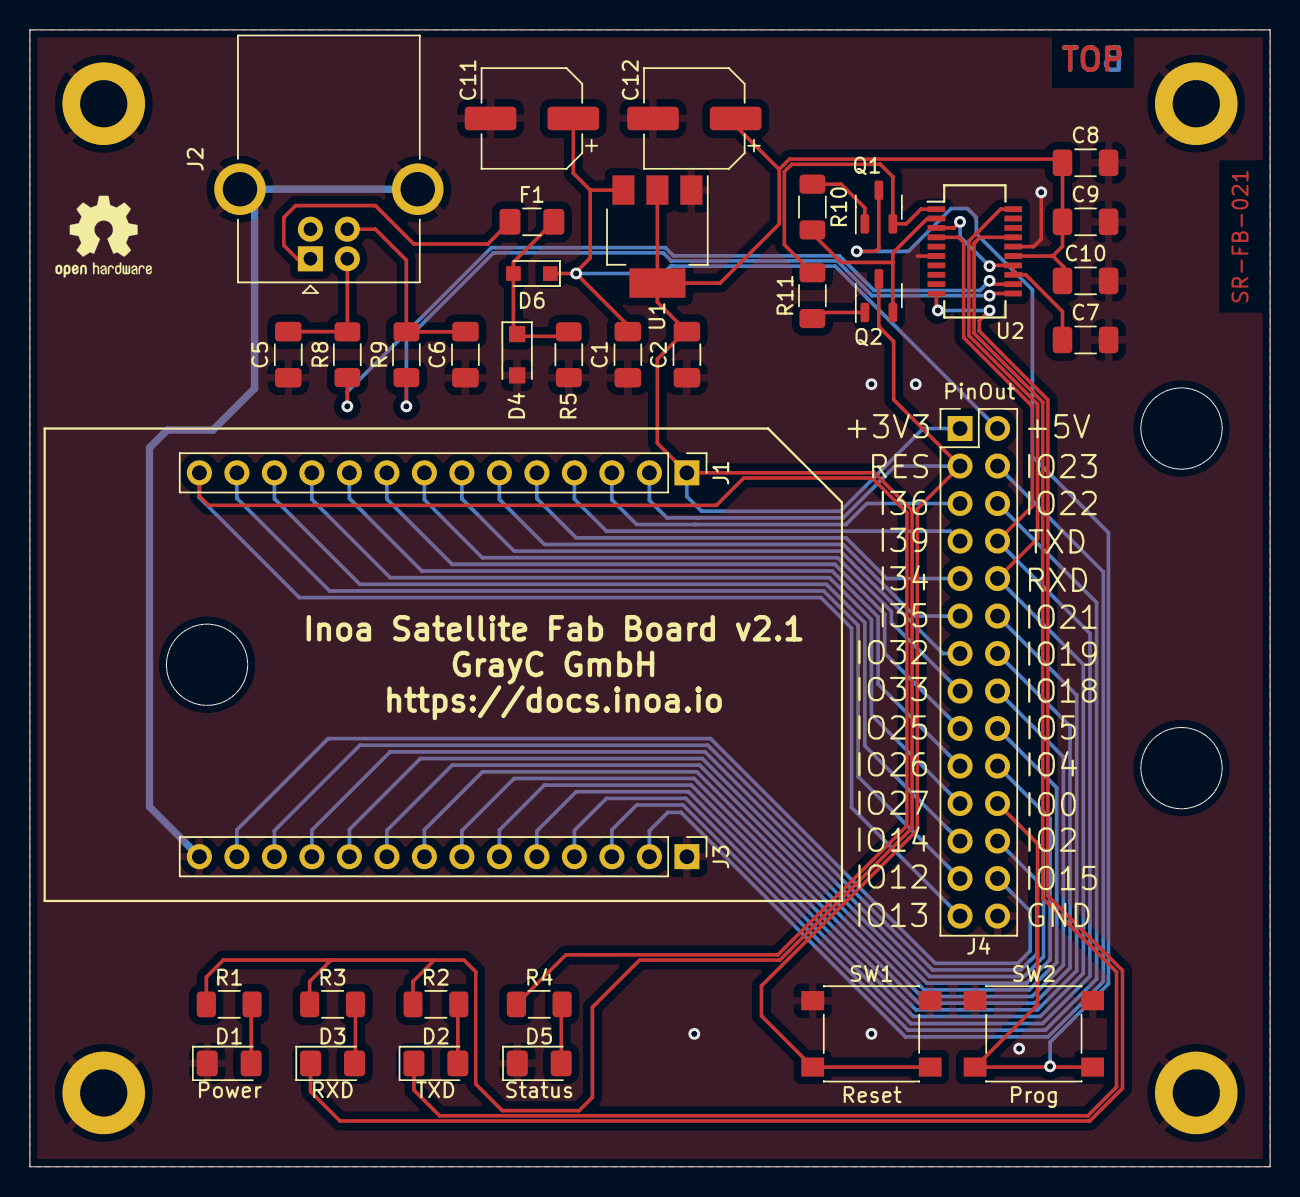
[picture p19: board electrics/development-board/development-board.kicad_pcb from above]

Board: 2 copper layers, 84.0 x 77.0 mm, 45 parts (0 on the bottom side), 45 nets.

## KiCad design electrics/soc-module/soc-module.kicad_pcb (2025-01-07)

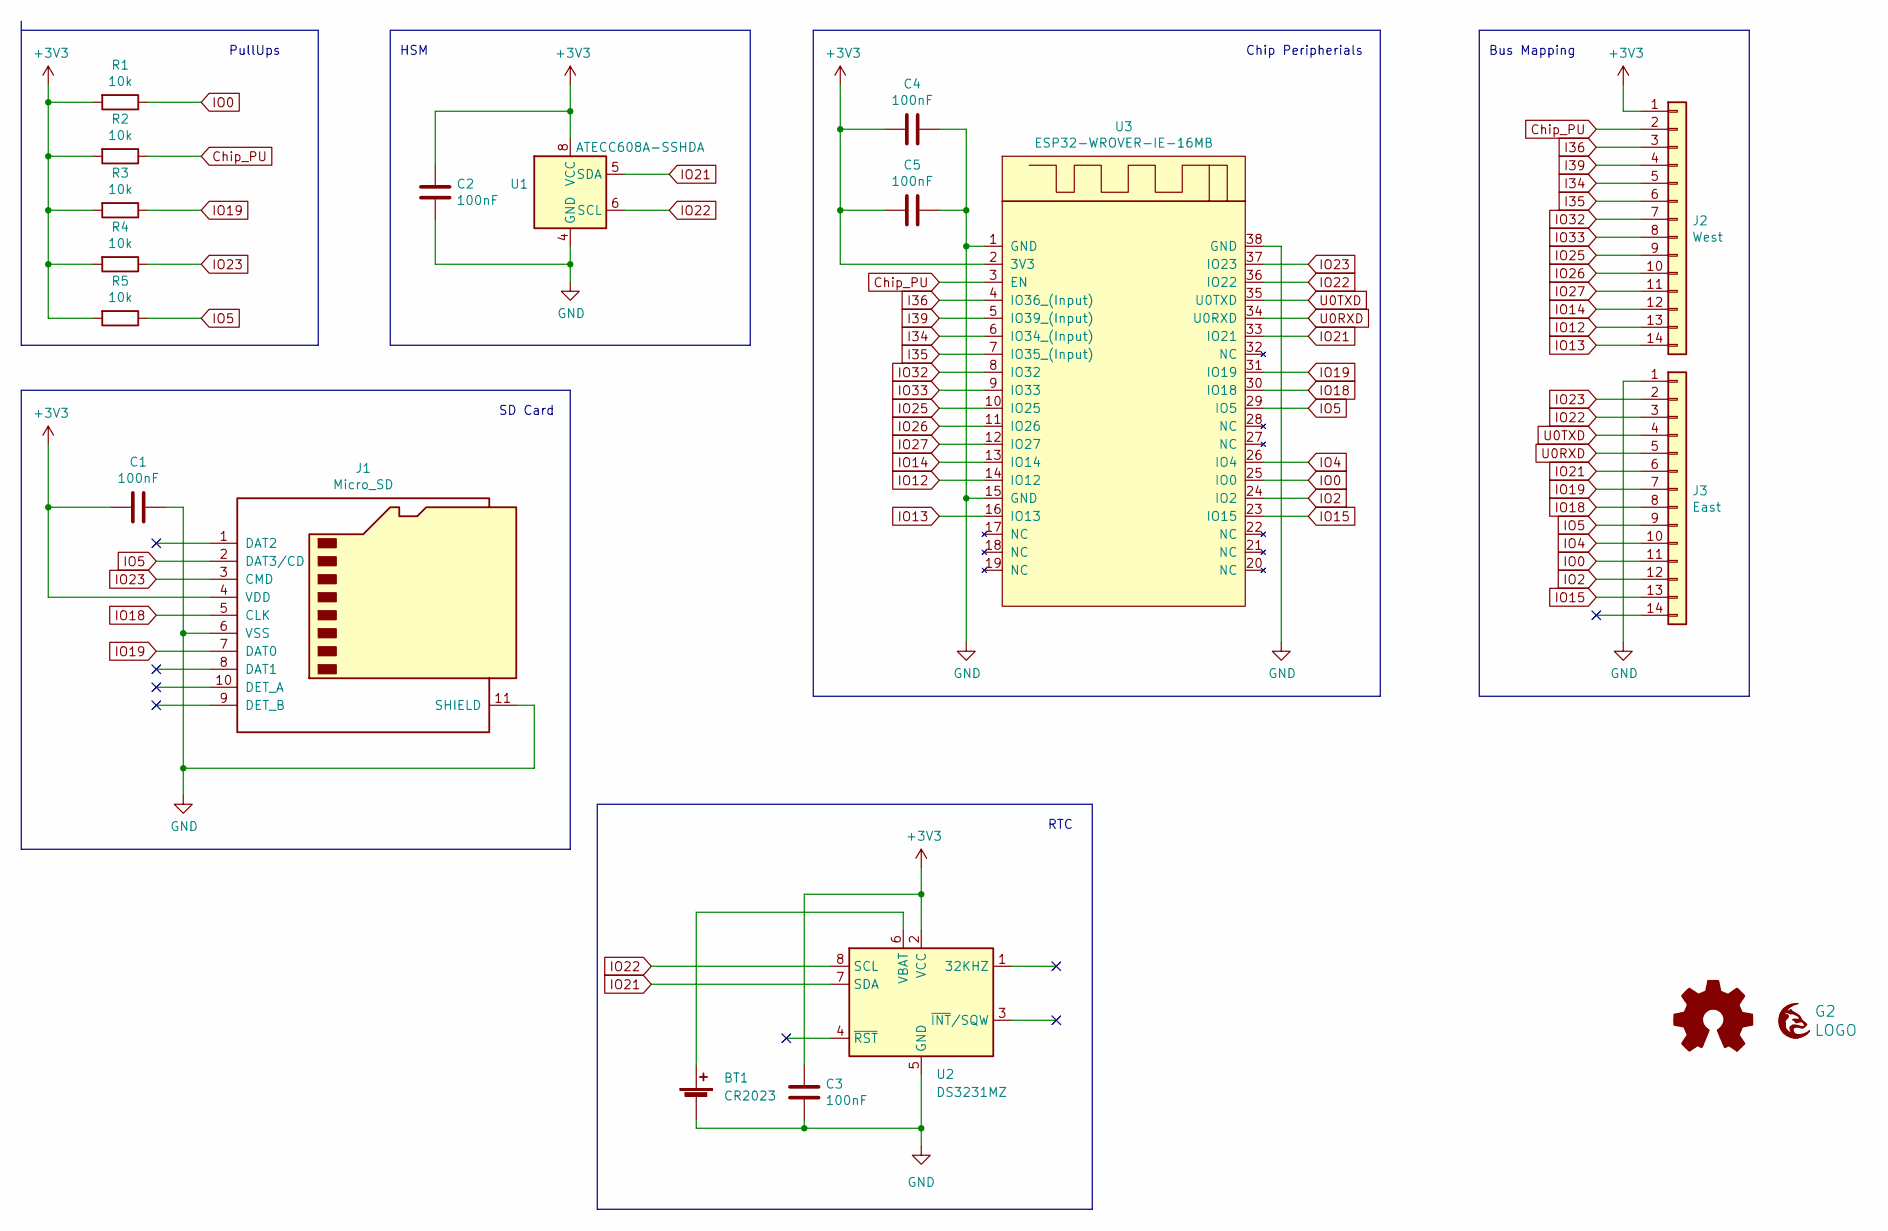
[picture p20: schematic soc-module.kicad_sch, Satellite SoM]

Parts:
BT1: CR2023; BatteryHolder_Keystone_1058_1x2032; mouser# 534-1058
C1, C2, C3, C4, C5: 100nF; C_1206_3216Metric_Pad1.33x1.80mm_HandSolder; mouser# 80-C1206C104M5R
G1: Logo_Open_Hardware_Small; OSHW-Logo2_7.3x6mm_SilkScreen
G2: LOGO; grayc-logo-negative
J1: Micro_SD; GCT_MEM2061-01-188-00-A_REVA; mouser# 640-MEM20610118800A
J2: West; PinHeader_1x14_P2.54mm_Vertical; mouser# 437-8018701453001101
J3: East; PinHeader_1x14_P2.54mm_Vertical; mouser# 437-8018701453001101
R1, R2, R3, R4, R5: 10k; R_1206_3216Metric_Pad1.30x1.75mm_HandSolder; mouser# 652-CR1206JW-103ELF
U1: ATECC608A-SSHDA; SOIC-8_3.9x4.9mm_P1.27mm; mouser# 556-ATECC608ASSHDAB
U2: DS3231MZ; SOIC-8_3.9x4.9mm_P1.27mm; mouser# 700-DS3231MZ+
U3: ESP32-WROVER-IE-16MB; ESP32-WROVER; mouser# 356-ESP32WRVIE2864UC

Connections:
+3V3: C1.2, C2.1, C3.1, C4.2, C5.2, J1.4 (VDD), J2.1, R1.2, R2.2, R3.2, R4.2, R5.2, U1.8 (VCC), U2.2 (VCC), U3.2 (3V3)
Chip_PU: J2.2, R2.1, U3.3 (EN)
GND: BT1.2 (-), C1.1, C2.2, C3.2, C4.1, C5.1, J1.6 (VSS), J1.11 (SHIELD), J3.1, U1.4 (GND), U2.5 (GND), U3.1 (GND), U3.15 (GND), U3.38 (GND)
I34: J2.5, U3.6 (IO34_(Input))
I35: J2.6, U3.7 (IO35_(Input))
I36: J2.3, U3.4 (IO36_(Input))
I39: J2.4, U3.5 (IO39_(Input))
IO0: J3.11, R1.1, U3.25 (IO0)
IO2: J3.12, U3.24 (IO2)
IO4: J3.10, U3.26 (IO4)
IO5: J1.2 (DAT3/CD), J3.9, R5.1, U3.29 (IO5)
IO12: J2.13, U3.14 (IO12)
IO13: J2.14, U3.16 (IO13)
IO14: J2.12, U3.13 (IO14)
IO15: J3.13, U3.23 (IO15)
IO18: J1.5 (CLK), J3.8, U3.30 (IO18)
IO19: J1.7 (DAT0), J3.7, R3.1, U3.31 (IO19)
IO21: J3.6, U1.5 (SDA), U2.7 (SDA), U3.33 (IO21)
IO22: J3.3, U1.6 (SCL), U2.8 (SCL), U3.36 (IO22)
IO23: J1.3 (CMD), J3.2, R4.1, U3.37 (IO23)
IO25: J2.9, U3.10 (IO25)
IO26: J2.10, U3.11 (IO26)
IO27: J2.11, U3.12 (IO27)
IO32: J2.7, U3.8 (IO32)
IO33: J2.8, U3.9 (IO33)
unnamed: BT1.1 (+), U2.6 (VBAT)
U0RXD: J3.5, U3.34 (U0RXD)
U0TXD: J3.4, U3.35 (U0TXD)

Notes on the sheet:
HSM
PullUps
Chip Peripherials
SD Card
RTC
Bus Mapping

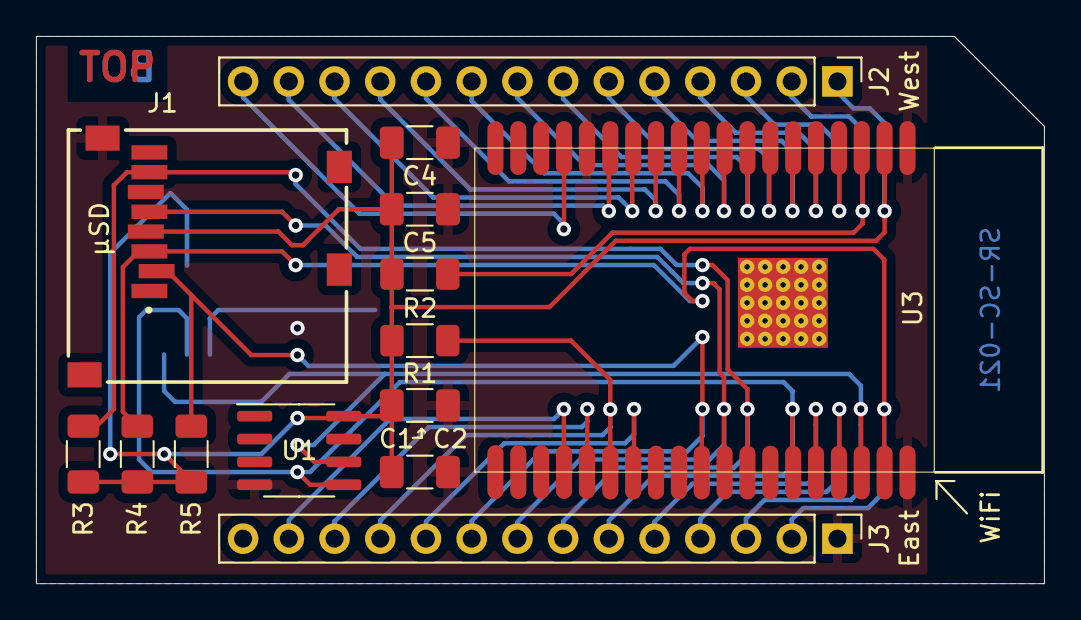
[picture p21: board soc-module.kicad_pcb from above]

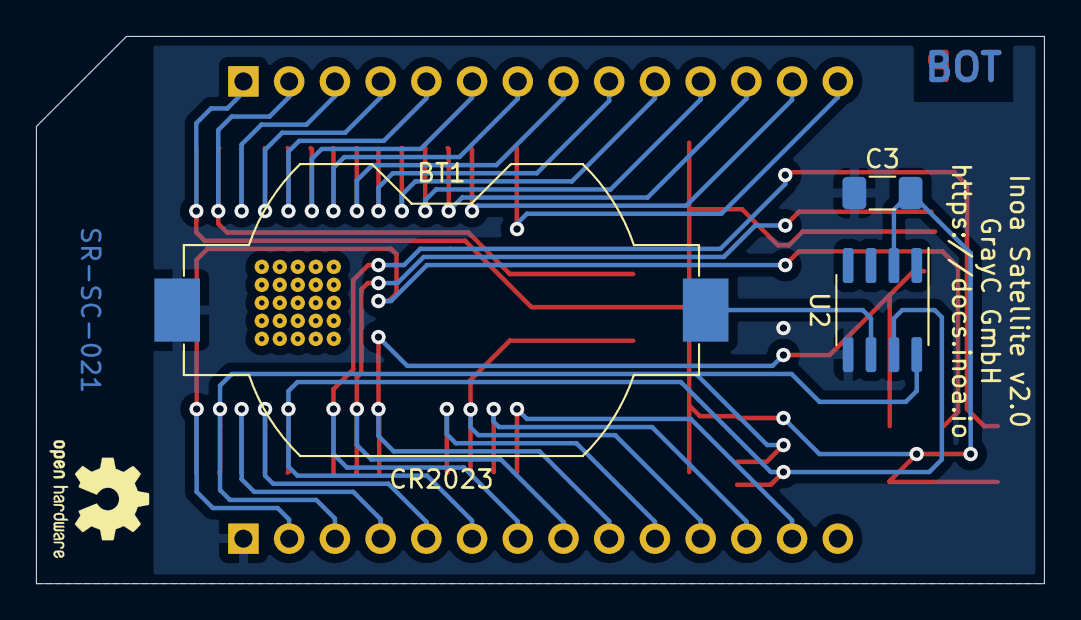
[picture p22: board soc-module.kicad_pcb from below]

Board: 2 copper layers, 56.0 x 30.4 mm, 19 parts (5 on the bottom side), 28 nets.

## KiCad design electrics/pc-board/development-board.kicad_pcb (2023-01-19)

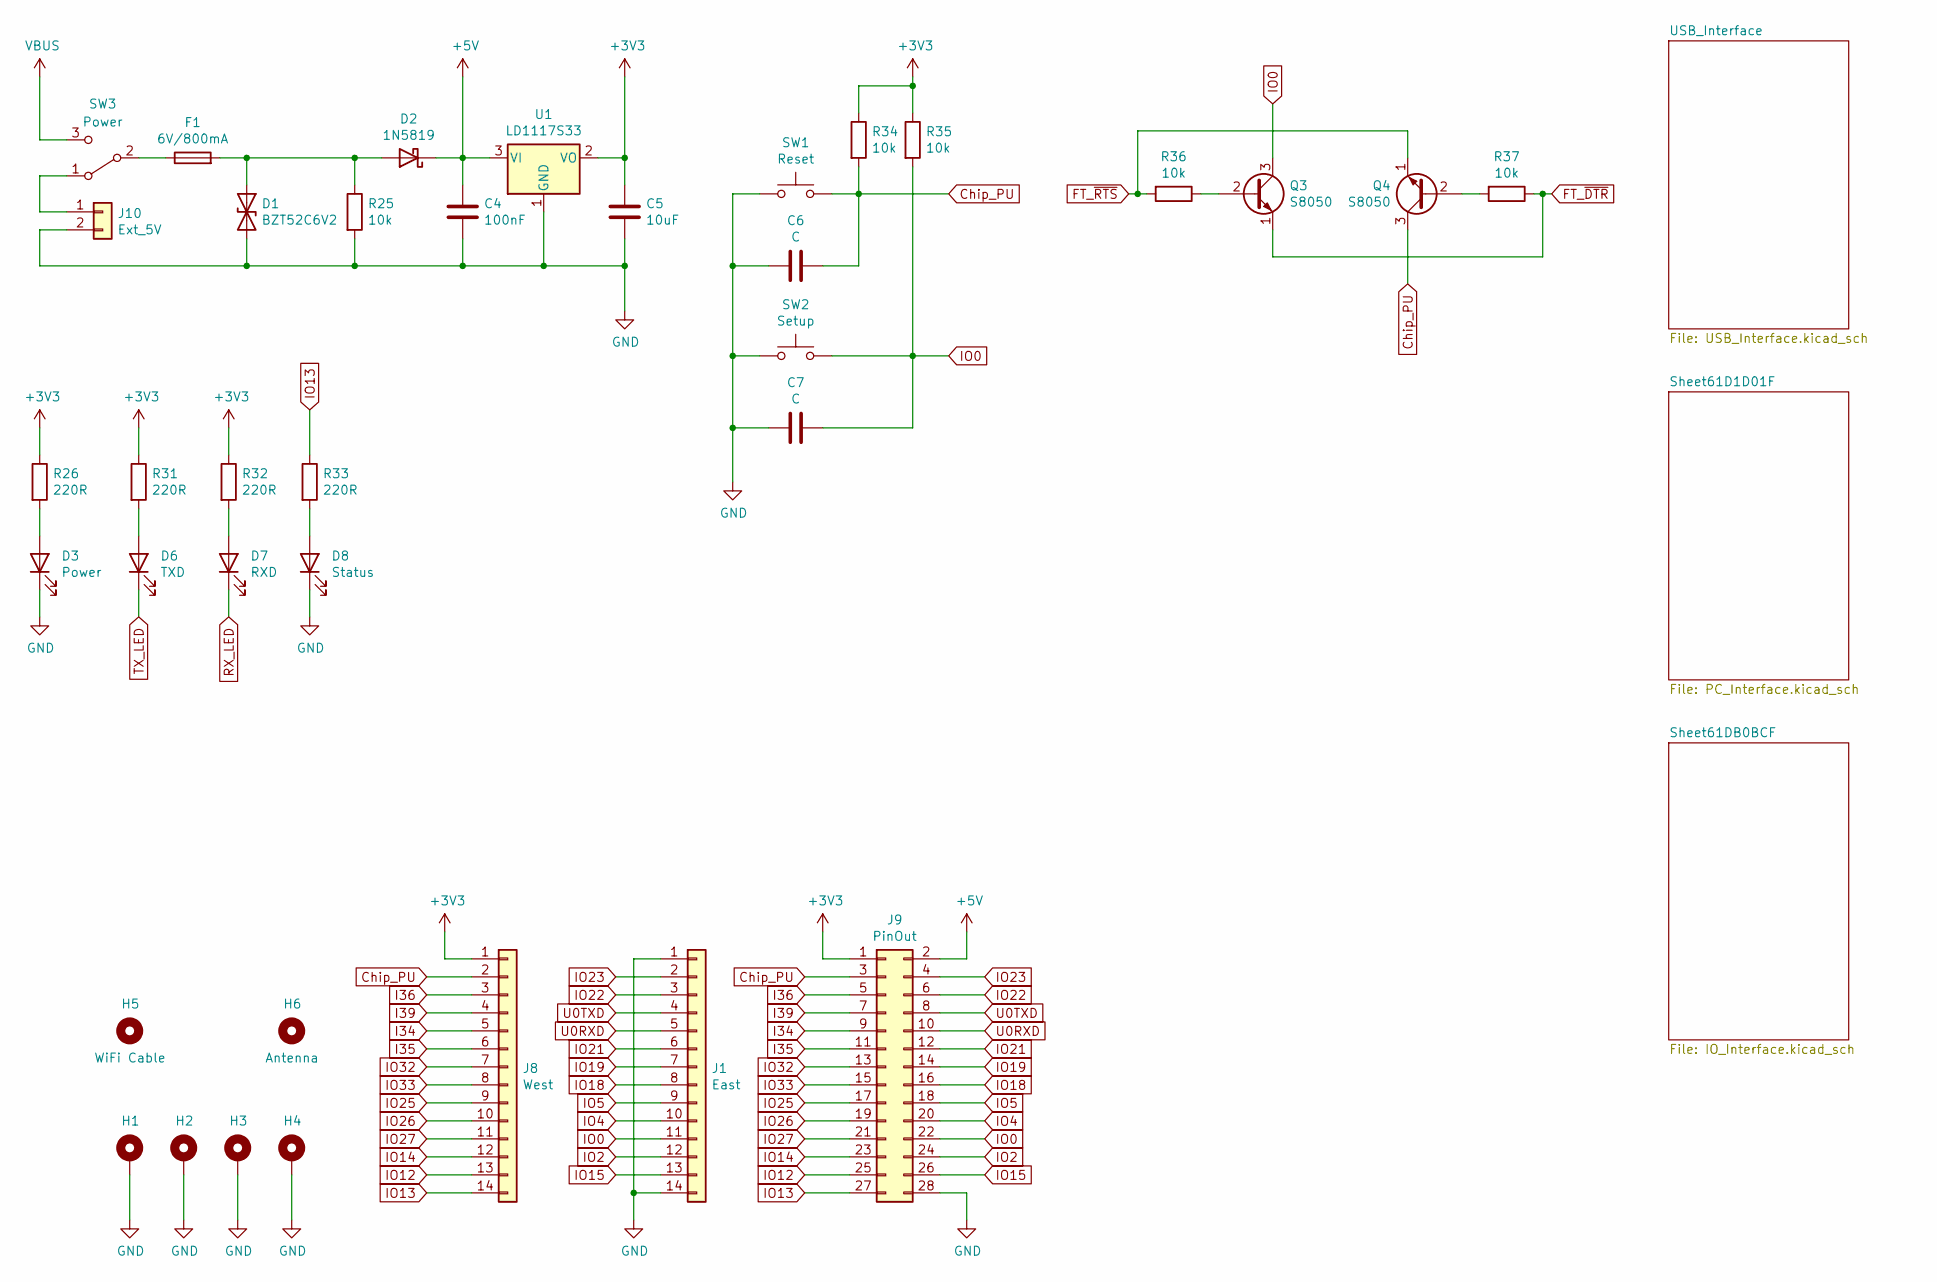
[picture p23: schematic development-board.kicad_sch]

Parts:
C4: 100nF; C_1206_3216Metric_Pad1.33x1.80mm_HandSolder
C5: 10uF; C_1206_3216Metric_Pad1.33x1.80mm_HandSolder
C6, C7: C; C_1206_3216Metric_Pad1.33x1.80mm_HandSolder
D1: BZT52C6V2; D_SOD-323_HandSoldering
D2: 1N5819; D_SOD-323_HandSoldering
D3: Power; LED_1206_3216Metric_Pad1.42x1.75mm_HandSolder
D6: TXD; LED_1206_3216Metric_Pad1.42x1.75mm_HandSolder
D7: RXD; LED_1206_3216Metric_Pad1.42x1.75mm_HandSolder
D8: Status; LED_1206_3216Metric_Pad1.42x1.75mm_HandSolder
F1: 6V/800mA; Fuse_1206_3216Metric_Pad1.42x1.75mm_HandSolder
H1, H2, H3, H4: MountingHole_Pad; MountingHole_3.2mm_M3_DIN965_Pad
H5: WiFi Cable; MountingHole_5.5mm
H6: Antenna; MountingHole_5.5mm
J1: East; PinHeader_1x14_P2.54mm_Vertical
J8: West; PinHeader_1x14_P2.54mm_Vertical
J9: PinOut; PinHeader_2x14_P2.54mm_Vertical
J10: Ext_5V; PinHeader_1x02_P2.54mm_Horizontal
Q3, Q4: S8050; SOT-23
R25, R34, R35, R36, R37: 10k; R_1206_3216Metric_Pad1.30x1.75mm_HandSolder
R26, R31, R32, R33: 220R; R_1206_3216Metric_Pad1.30x1.75mm_HandSolder
SW1: Reset; SW_SPST_PTS645
SW2: Setup; SW_SPST_PTS645
SW3: Power; SW_E-Switch_EG1224_SPDT_Angled
U1: LD1117S33; SOT-223-3_TabPin2

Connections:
+3V3: C5.1, J8.1, J9.1, R26.1, R31.1, R32.1, R34.1, R35.1, U1.2 (VO); also elsewhere on the board
+5V: C4.1, D2.1 (K), J9.2, U1.3 (VI); also elsewhere on the board
Chip_PU: C6.1, J8.2, J9.3, Q4.3 (C), R34.2, SW1.2
FT_~DTR: Q3.1 (E), R37.1; also elsewhere on the board
FT_~RTS: Q4.1 (E), R36.2; also elsewhere on the board
GND: C4.2, C5.2, C6.2, C7.2, D1.2 (A2), D3.1 (K), D8.1 (K), H1.1, H2.1, H3.1, H4.1, J1.1, J1.14, J9.28, J10.2, R25.2, SW1.1, SW2.1, U1.1 (GND); also elsewhere on the board
I34: J8.5, J9.9
I35: J8.6, J9.11
I36: J8.3, J9.5
I39: J8.4, J9.7
IO0: C7.1, J1.11, J9.22, Q3.3 (C), R35.2, SW2.2
IO2: J1.12, J9.24
IO4: J1.10, J9.20; also elsewhere on the board
IO5: J1.9, J9.18; also elsewhere on the board
IO12: J8.13, J9.25
IO13: J8.14, J9.27, R33.1
IO14: J8.12, J9.23
IO15: J1.13, J9.26; also elsewhere on the board
IO18: J1.8, J9.16; also elsewhere on the board
IO19: J1.7, J9.14; also elsewhere on the board
IO21: J1.6, J9.12; also elsewhere on the board
IO22: J1.3, J9.6; also elsewhere on the board
IO23: J1.2, J9.4; also elsewhere on the board
IO25: J8.9, J9.17; also elsewhere on the board
IO26: J8.10, J9.19; also elsewhere on the board
IO27: J8.11, J9.21; also elsewhere on the board
IO32: J8.7, J9.13; also elsewhere on the board
IO33: J8.8, J9.15; also elsewhere on the board
unnamed: D1.1 (A1), D2.2 (A), F1.2, R25.1
unnamed: D3.2 (A), R26.2
unnamed: D6.2 (A), R31.2
unnamed: D7.2 (A), R32.2
unnamed: D8.2 (A), R33.2
unnamed: F1.1, SW3.2 (B)
unnamed: J10.1, SW3.1 (A)
unnamed: Q3.2 (B), R36.1
unnamed: Q4.2 (B), R37.2
RX_LED: D7.1 (K); also elsewhere on the board
TX_LED: D6.1 (K); also elsewhere on the board
U0RXD: J1.5, J9.10
U0TXD: J1.4, J9.8
VBUS: SW3.3 (C); also elsewhere on the board

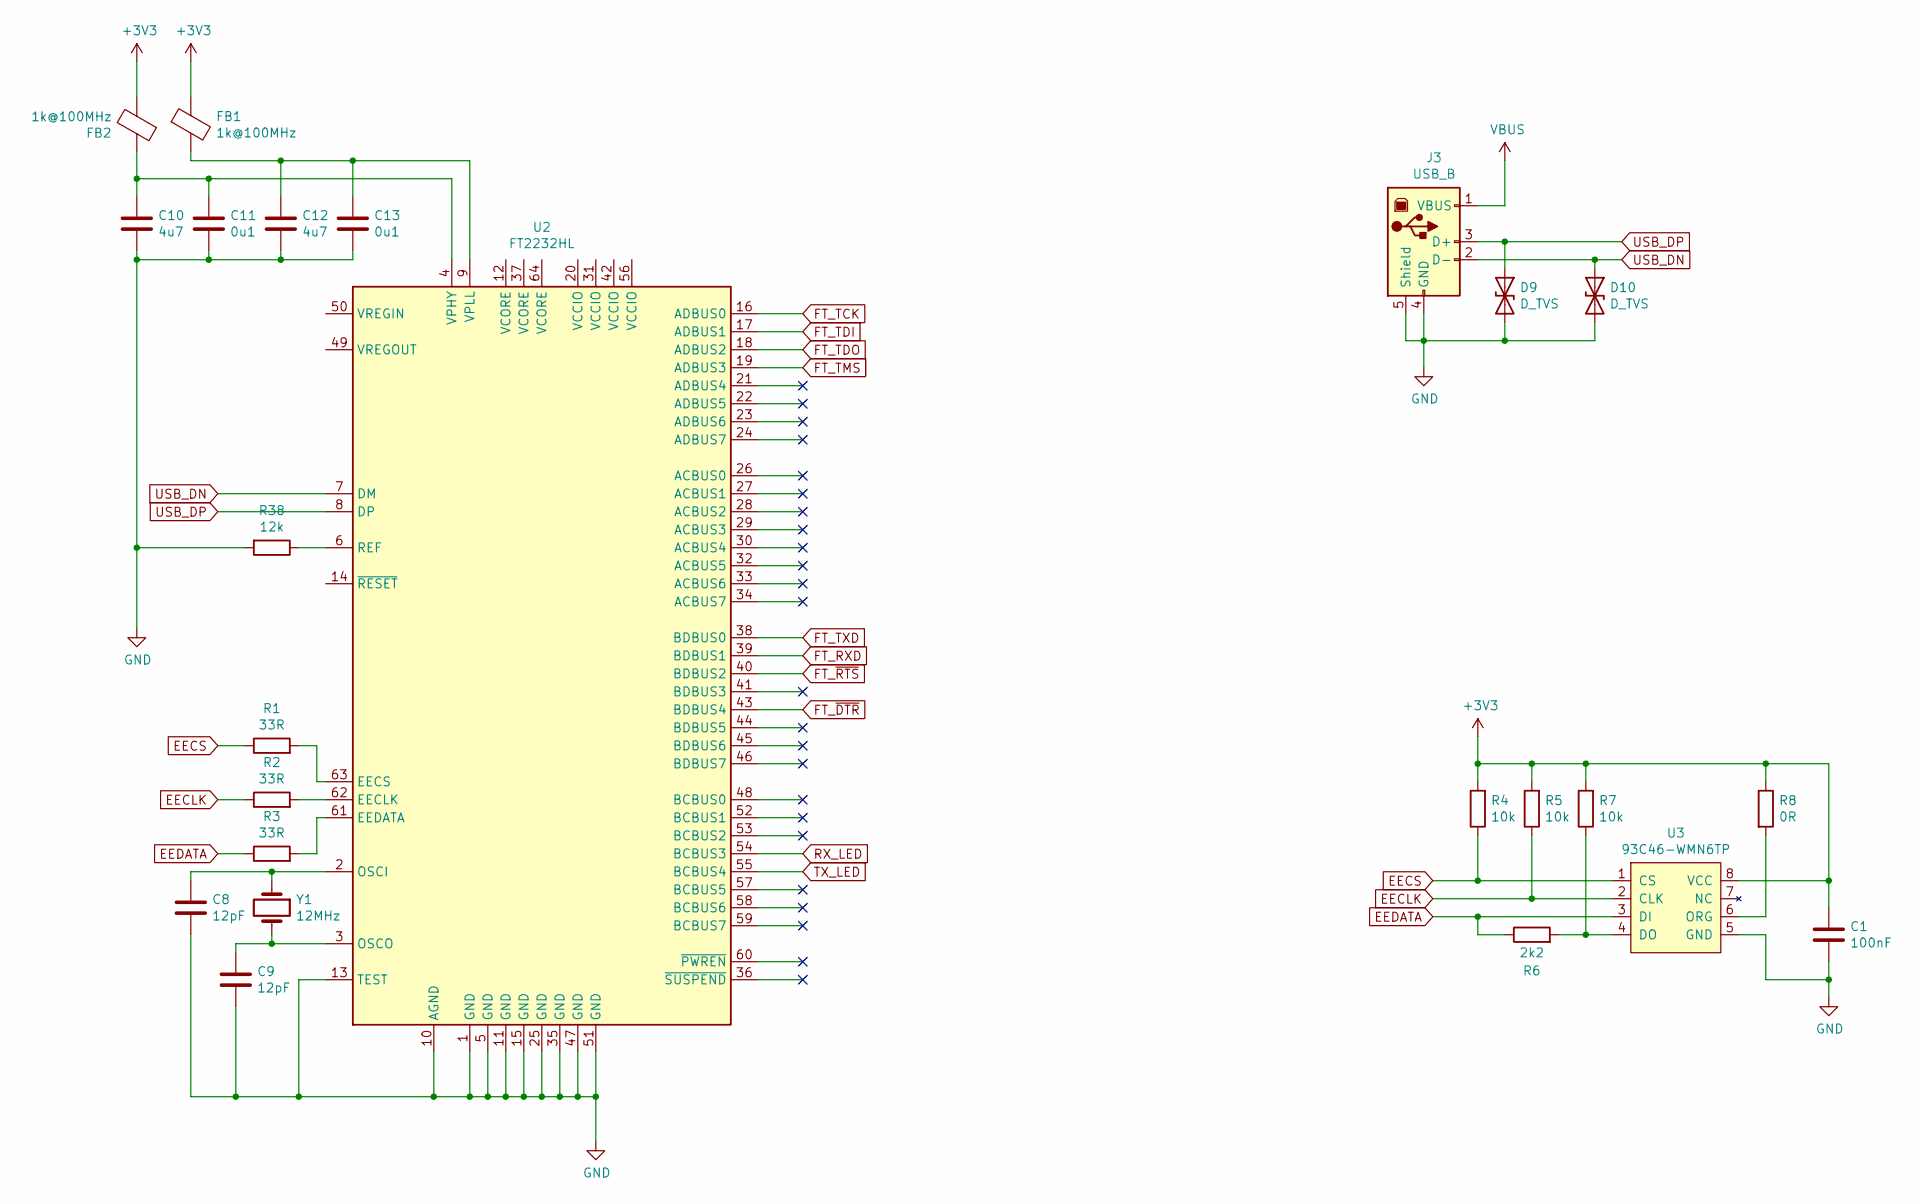
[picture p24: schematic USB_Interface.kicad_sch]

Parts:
C1: 100nF; C_1206_3216Metric_Pad1.33x1.80mm_HandSolder
C8, C9: 12pF; C_1206_3216Metric_Pad1.33x1.80mm_HandSolder
C10, C12: 4u7; C_1206_3216Metric_Pad1.33x1.80mm_HandSolder
C11, C13: 0u1; C_1206_3216Metric_Pad1.33x1.80mm_HandSolder
D9, D10: D_TVS; D_0603_1608Metric_Pad1.05x0.95mm_HandSolder
FB1, FB2: 1k@100MHz; R_1206_3216Metric_Pad1.30x1.75mm_HandSolder
J3: USB_B; USB_B_OST_USB-B1HSxx_Horizontal
R1, R2, R3: 33R; R_1206_3216Metric_Pad1.30x1.75mm_HandSolder
R4, R5, R7: 10k; R_1206_3216Metric_Pad1.30x1.75mm_HandSolder
R6: 2k2; R_1206_3216Metric_Pad1.30x1.75mm_HandSolder
R8: 0R; R_1206_3216Metric_Pad1.30x1.75mm_HandSolder
R38: 12k; R_1206_3216Metric_Pad1.30x1.75mm_HandSolder
U2: FT2232HL; LQFP-64_10x10mm_P0.5mm
U3: 93C46-WMN6TP; SOIC-8_3.9x4.9mm_P1.27mm
Y1: 12MHz; Crystal_SMD_HC49-SD_HandSoldering

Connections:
+3V3: C1.1, FB1.1, FB2.2, R4.2, R5.2, R7.2, R8.1, U3.8 (VCC); also elsewhere on the board
EECLK: R2.1, R5.1, U3.2 (CLK)
EECS: R1.1, R4.1, U3.1 (CS)
EEDATA: R3.1, R6.1, U3.3 (DI)
FT_RXD: U2.39 (BDBUS1)
FT_TCK: U2.16 (ADBUS0)
FT_TDI: U2.17 (ADBUS1)
FT_TDO: U2.18 (ADBUS2)
FT_TMS: U2.19 (ADBUS3)
FT_TXD: U2.38 (BDBUS0)
FT_~DTR: U2.43 (BDBUS4); also elsewhere on the board
FT_~RTS: U2.40 (BDBUS2); also elsewhere on the board
GND: C1.2, C8.2, C9.2, C10.2, C11.2, C12.2, C13.2, D9.2 (A2), D10.2 (A2), J3.4 (GND), J3.5 (Shield), R38.2, U2.1 (GND), U2.5 (GND), U2.10 (AGND), U2.11 (GND), U2.13 (TEST), U2.15 (GND), U2.25 (GND), U2.35 (GND), U2.47 (GND), U2.51 (GND), U3.5 (GND); also elsewhere on the board
unnamed: C8.1, U2.2 (OSCI), Y1.1
unnamed: C9.1, U2.3 (OSCO), Y1.2
unnamed: C10.1, C11.1, FB2.1, U2.4 (VPHY)
unnamed: C12.1, C13.1, FB1.2, U2.9 (VPLL)
unnamed: R1.2, U2.63 (EECS)
unnamed: R2.2, U2.62 (EECLK)
unnamed: R3.2, U2.61 (EEDATA)
unnamed: R6.2, R7.1, U3.4 (DO)
unnamed: R8.2, U3.6 (ORG)
unnamed: R38.1, U2.6 (REF)
RX_LED: U2.54 (BCBUS3); also elsewhere on the board
TX_LED: U2.55 (BCBUS4); also elsewhere on the board
USB_DN: D10.1 (A1), J3.2 (D-), U2.7 (DM)
USB_DP: D9.1 (A1), J3.3 (D+), U2.8 (DP)
VBUS: J3.1 (VBUS); also elsewhere on the board

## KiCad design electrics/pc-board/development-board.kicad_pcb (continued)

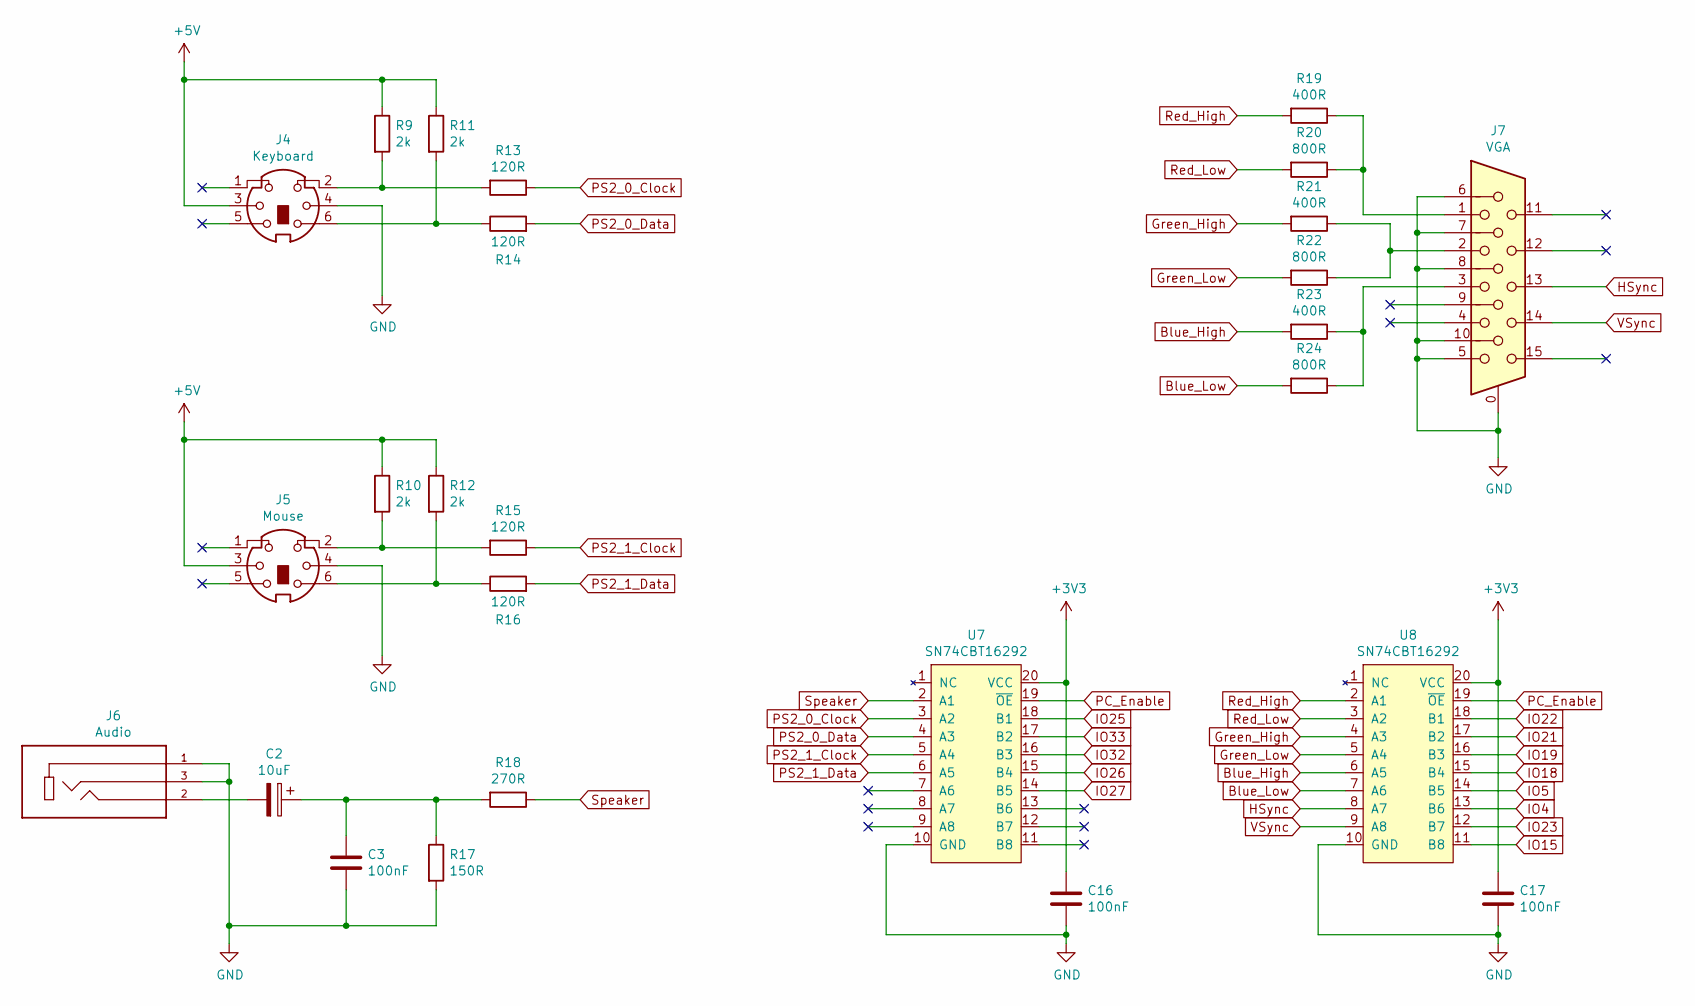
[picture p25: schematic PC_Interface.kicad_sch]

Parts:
C2: 10uF; CP_EIA-3216-18_Kemet-A_Pad1.58x1.35mm_HandSolder
C3, C16, C17: 100nF; C_1206_3216Metric_Pad1.33x1.80mm_HandSolder
J4: Keyboard; TE_5749180-1
J5: Mouse; TE_5749180-1
J6: Audio; CUI_SJ1-3523N; PARTREV 1.02
J7: VGA; AMPHENOL_L77HDE15SD1CH4F
R9, R10, R11, R12: 2k; R_1206_3216Metric_Pad1.30x1.75mm_HandSolder
R13, R14, R15, R16: 120R; R_1206_3216Metric_Pad1.30x1.75mm_HandSolder
R17: 150R; R_1206_3216Metric_Pad1.30x1.75mm_HandSolder
R18: 270R; R_1206_3216Metric_Pad1.30x1.75mm_HandSolder
R19, R21, R23: 400R; R_1206_3216Metric_Pad1.30x1.75mm_HandSolder
R20, R22, R24: 800R; R_1206_3216Metric_Pad1.30x1.75mm_HandSolder
U7, U8: SN74CBT16292; TSSOP-20_4.4x6.5mm_P0.65mm

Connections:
+3V3: C16.1, C17.1, U7.20 (VCC), U8.20 (VCC); also elsewhere on the board
+5V: J4.3, J5.3, R9.1, R10.1, R11.1, R12.1; also elsewhere on the board
Blue_High: R23.2, U8.6 (A5)
Blue_Low: R24.2, U8.7 (A6)
GND: C3.2, C16.2, C17.2, J4.4, J5.4, J6.1, J6.3, J7.0, J7.5, J7.6, J7.7, J7.8, J7.10, R17.2, U7.10 (GND), U8.10 (GND); also elsewhere on the board
Green_High: R21.2, U8.4 (A3)
Green_Low: R22.2, U8.5 (A4)
HSync: J7.13, U8.8 (A7)
IO4: U8.13 (B6); also elsewhere on the board
IO5: U8.14 (B5); also elsewhere on the board
IO15: U8.11 (B8); also elsewhere on the board
IO18: U8.15 (B4); also elsewhere on the board
IO19: U8.16 (B3); also elsewhere on the board
IO21: U8.17 (B2); also elsewhere on the board
IO22: U8.18 (B1); also elsewhere on the board
IO23: U8.12 (B7); also elsewhere on the board
IO25: U7.18 (B1); also elsewhere on the board
IO26: U7.15 (B4); also elsewhere on the board
IO27: U7.14 (B5); also elsewhere on the board
IO32: U7.16 (B3); also elsewhere on the board
IO33: U7.17 (B2); also elsewhere on the board
unnamed: C2.1, C3.1, R17.1, R18.2
unnamed: C2.2, J6.2
unnamed: J4.2, R9.2, R13.2
unnamed: J4.6, R11.2, R14.1
unnamed: J5.2, R10.2, R15.2
unnamed: J5.6, R12.2, R16.1
unnamed: J7.1, R19.1, R20.1
unnamed: J7.2, R21.1, R22.1
unnamed: J7.3, R23.1, R24.1
PC_Enable: U7.19 (~OE), U8.19 (~OE)
PS2_0_Clock: R13.1, U7.3 (A2)
PS2_0_Data: R14.2, U7.4 (A3)
PS2_1_Clock: R15.1, U7.5 (A4)
PS2_1_Data: R16.2, U7.6 (A5)
Red_High: R19.2, U8.2 (A1)
Red_Low: R20.2, U8.3 (A2)
Speaker: R18.1, U7.2 (A1)
VSync: J7.14, U8.9 (A8)

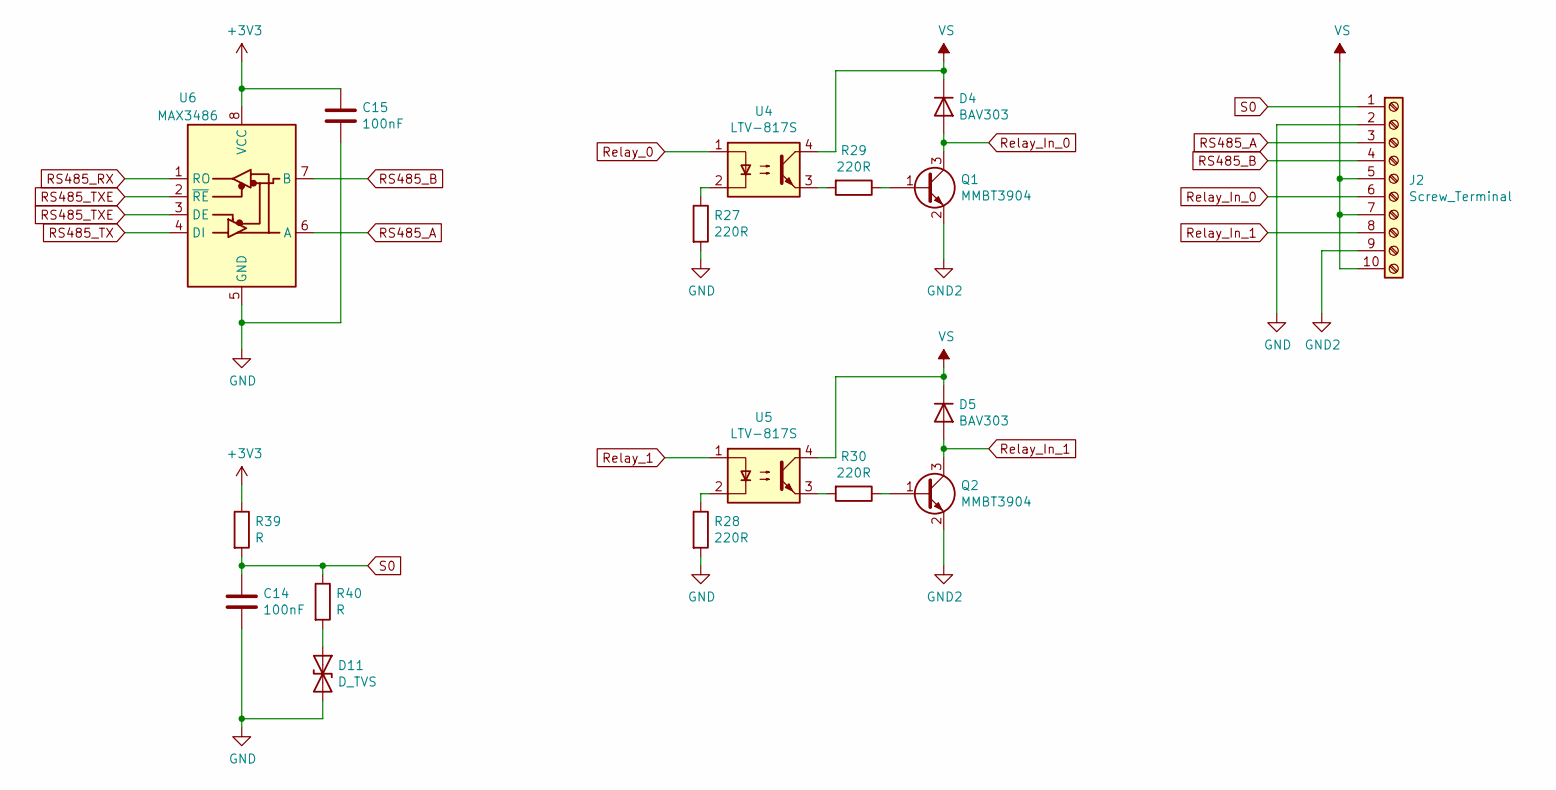
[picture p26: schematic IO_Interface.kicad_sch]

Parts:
C14, C15: 100nF; C_1206_3216Metric_Pad1.33x1.80mm_HandSolder
D4, D5: BAV303; D_MicroMELF
D11: D_TVS; D_0603_1608Metric_Pad1.05x0.95mm_HandSolder
J2: Screw_Terminal; TE_1-1776113-0
Q1, Q2: MMBT3904; SOT-23
R27, R28, R29, R30: 220R; R_1206_3216Metric_Pad1.30x1.75mm_HandSolder
R39, R40: R; R_1206_3216Metric_Pad1.30x1.75mm_HandSolder
U4, U5: LTV-817S; SMDIP-4_W9.53mm
U6: MAX3486; SOIC-8_3.9x4.9mm_P1.27mm

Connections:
+3V3: C15.1, R39.1, U6.8 (VCC); also elsewhere on the board
GND: C14.2, C15.2, D11.2 (A2), J2.2, R27.2, R28.2, U6.5 (GND); also elsewhere on the board
GND2: J2.9, Q1.2 (E), Q2.2 (E)
unnamed: D11.1 (A1), R40.2
unnamed: Q1.1 (B), R29.1
unnamed: Q2.1 (B), R30.1
unnamed: R27.1, U4.2
unnamed: R28.1, U5.2
unnamed: R29.2, U4.3
unnamed: R30.2, U5.3
RS485_A: J2.3, U6.6 (A)
RS485_B: J2.4, U6.7 (B)
RS485_RX: U6.1 (RO)
RS485_TX: U6.4 (DI)
RS485_TXE: U6.2 (~RE), U6.3 (DE)
Relay_0: U4.1
Relay_1: U5.1
Relay_In_0: D4.2 (A), J2.6, Q1.3 (C)
Relay_In_1: D5.2 (A), J2.8, Q2.3 (C)
S0: C14.1, J2.1, R39.2, R40.1
VS: D4.1 (K), D5.1 (K), J2.5, J2.7, J2.10, U4.4, U5.4

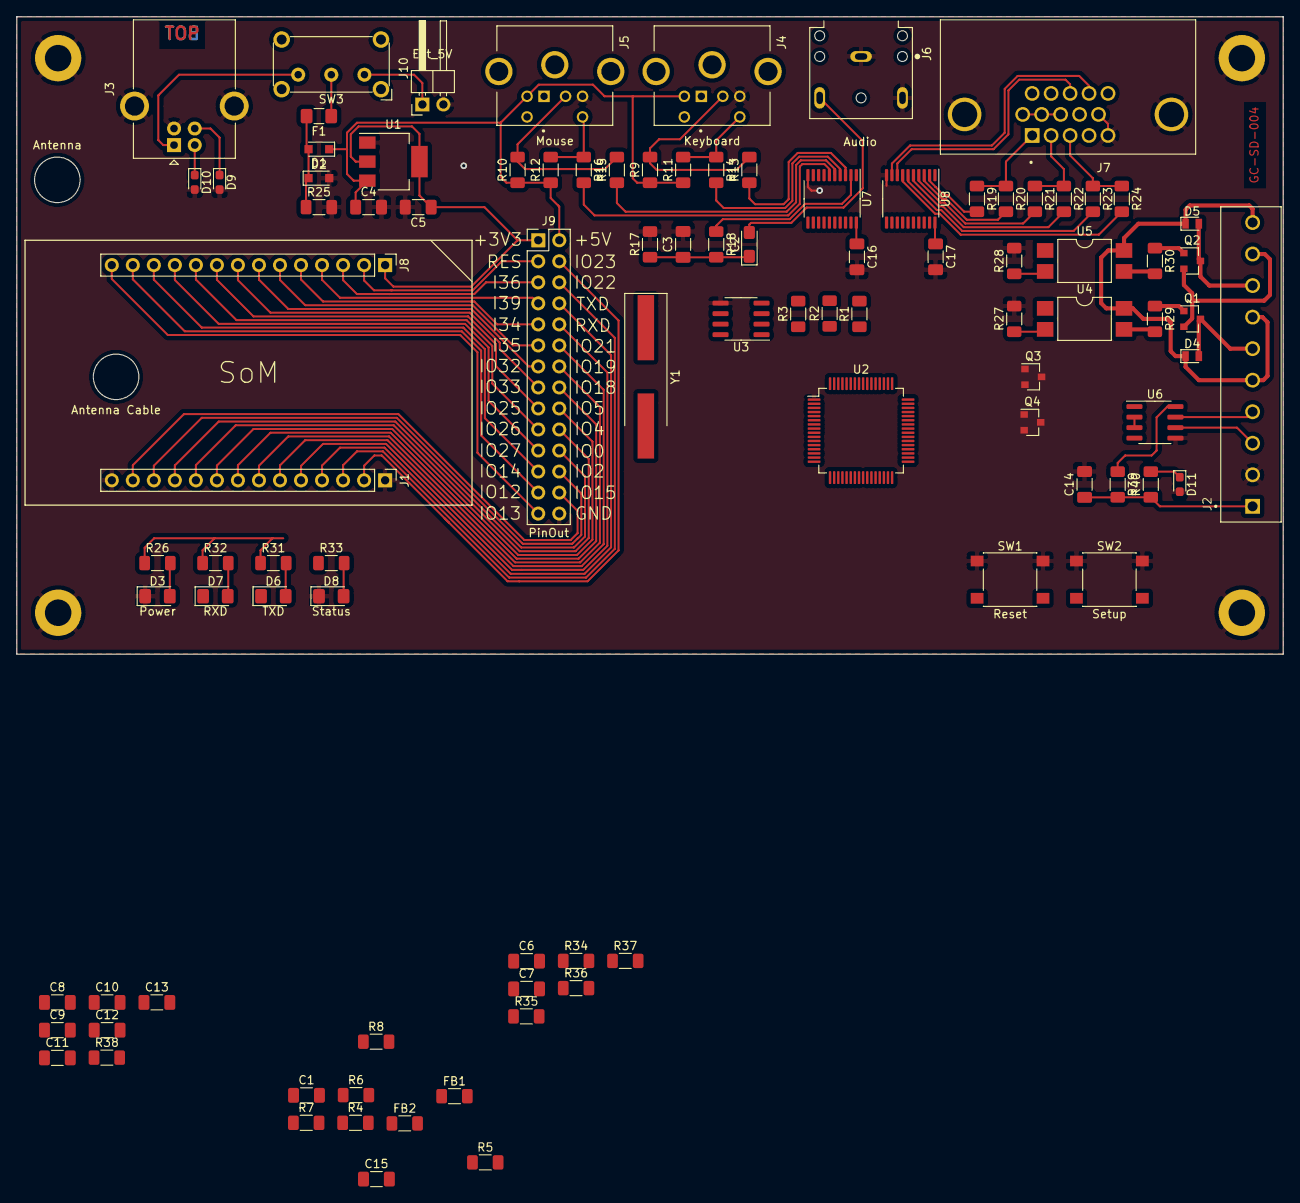
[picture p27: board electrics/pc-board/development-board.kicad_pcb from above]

Board: 2 copper layers, 153.0 x 77.0 mm, 103 parts (0 on the bottom side), 95 nets.

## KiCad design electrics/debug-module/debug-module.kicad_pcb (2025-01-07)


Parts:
C1, C2: 47pF; C_1206_3216Metric_Pad1.33x1.80mm_HandSolder
C3: 4u7; C_1206_3216Metric_Pad1.33x1.80mm_HandSolder
C4, C5, C6, C7: 100nF; C_1206_3216Metric_Pad1.33x1.80mm_HandSolder
C9: 10uF; C_1206_3216Metric_Pad1.33x1.80mm_HandSolder
D1: MM3Z6V2T1G; D_SOD-123F
D2, D3: 1N5819; D_SOD-323_HandSoldering
D5: Power; LED_1206_3216Metric_Pad1.42x1.75mm_HandSolder
D6: Status; LED_1206_3216Metric_Pad1.42x1.75mm_HandSolder
D7: TXD; LED_1206_3216Metric_Pad1.42x1.75mm_HandSolder
D8: RXD; LED_1206_3216Metric_Pad1.42x1.75mm_HandSolder
F1: 5V/1A; Fuse_1206_3216Metric_Pad1.42x1.75mm_HandSolder
G1: LOGO; grayc-logo-negative
J1: East; PinSocket_1x14_P2.54mm_Vertical
J2: West; PinSocket_1x14_P2.54mm_Vertical
J3: USB; USB_Micro-B_Wuerth_614105150721_Vertical_CircularHoles
LOGO1: Logo_Open_Hardware_Small; OSHW-Logo_5.7x6mm_SilkScreen
Q1, Q2: S8050; SOT-23-3
R1, R2: 27R; R_1206_3216Metric_Pad1.30x1.75mm_HandSolder
R3, R4, R5: 10k; R_1206_3216Metric_Pad1.30x1.75mm_HandSolder
R6, R7, R8, R9: 220R; R_1206_3216Metric_Pad1.30x1.75mm_HandSolder
SW1: Reset; SW_SPST_PTS645
SW2: Prog; SW_SPST_PTS645
U1: FT231XS; SSOP-20_3.9x8.7mm_P0.635mm
U2: LD1117S33; SOT-223-3_TabPin2

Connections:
+3V3: C3.1, C4.1, C5.1, C9.1, D3.2 (A), R6.2, R8.2, R9.2, U1.15 (VCC), U2.2 (VO)
Chip_PU: J2.2, Q2.3 (C), SW1.2 (B)
D+: C2.1, J3.3 (D+), R2.2
D-: C1.1, J3.2 (D-), R1.2
FT_~DTR: Q1.2 (E), R5.2, U1.1 (~DTR)
FT_~RTS: Q2.2 (E), R4.2, U1.2 (~RTS)
GND: C1.2, C2.2, C3.2, C4.2, C5.2, C6.2, C7.2, C9.2, D1.2 (A), D5.1 (K), D6.1 (K), J1.1, J1.14, J3.5 (GND), J3.6 (Shield), R3.1, SW1.1 (A), SW2.1 (A), U1.6 (GND), U1.16 (GND), U2.1 (GND)
IO0: J1.11, Q1.3 (C), SW2.2 (B)
IO13: J2.14, R7.2
unnamed: C6.1, U1.3 (VCCIO), U1.13 (3V3OUT), U1.14 (~RESET)
unnamed: C7.1, D2.1 (K), U2.3 (VI)
unnamed: D1.1 (K), D2.2 (A), F1.2, R3.2
unnamed: D5.2 (A), R6.1
unnamed: D6.2 (A), R7.1
unnamed: D7.2 (A), R8.1
unnamed: D8.2 (A), R9.1
unnamed: F1.1, J3.1 (VBUS)
unnamed: D3.1 (K), J2.1
unnamed: Q1.1 (B), R4.1
unnamed: Q2.1 (B), R5.1
unnamed: R1.1, U1.12 (USBDM)
unnamed: R2.1, U1.11 (USBDP)
RX_LED: D8.1 (K), U1.10 (CBUS2)
TX_LED: D7.1 (K), U1.17 (CBUS1)
U0RXD: J1.5, U1.20 (TXD)
U0TXD: J1.4, U1.4 (RXD)



Board: 2 copper layers, 40.6 x 30.4 mm, 36 parts (11 on the bottom side), 26 nets.

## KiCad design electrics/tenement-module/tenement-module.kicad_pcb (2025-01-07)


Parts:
C1, C2, C4, C7: 100nF; C_1206_3216Metric_Pad1.33x1.80mm_HandSolder
C3: 100nF / 35V; C_1206_3216Metric_Pad1.33x1.80mm_HandSolder
C5: 100uF; C_1206_3216Metric_Pad1.33x1.80mm_HandSolder
D1, D2: D_TVS; D_0603_1608Metric_Pad1.05x0.95mm_HandSolder
D3: 25V; D_SOD-523
D4: 1N5819; D_SOD-323_HandSoldering
F1: 25V/1A; Fuse_1206_3216Metric_Pad1.42x1.75mm_HandSolder
G1: Logo_Open_Hardware_Small; OSHW-Logo2_7.3x6mm_SilkScreen
G2: LOGO; grayc-logo-negative
J1: WMBus; IPEX_20279-001E-01
J2: North; PHOENIX_1935200; mouser# 651-1935200
J3: West; PinHeader_1x14_P2.54mm_Vertical
J4: East; PinHeader_1x14_P2.54mm_Vertical
R1, R2, R5: 10k; R_1206_3216Metric_Pad1.30x1.75mm_HandSolder
R3, R4: 220R; R_1206_3216Metric_Pad1.30x1.75mm_HandSolder
U1: BA033CC0FP-E2; TO-252-3_TabPin2
U3: WIRL-WMB8
U4: MAX3486; SOIC-8_3.9x4.9mm_P1.27mm

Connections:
+3V3: C4.1, C5.1, C7.1, J3.1, R1.2, R2.2, U1.3 (Output), U3.3 (VCC), U4.8 (VCC)
GND: C1.2, C2.2, C3.2, C4.2, C5.2, C7.2, D1.2 (A2), D2.2 (A2), D3.2 (A), J1.2 (Ext), J2.5, J4.1, R5.2, U1.2 (GND), U3.2 (GND), U3.7 (~CTS), U3.23 (GND), U4.5 (GND)
GNDPWR: J4.14
unnamed: C3.1, D4.1 (K), U1.1 (Input)
unnamed: D1.1 (A1), R3.1
unnamed: D2.1 (A1), R4.1
unnamed: D3.1 (K), D4.2 (A), F1.1, R5.1
RS485_0_A: J2.4, U4.6 (A)
RS485_0_B: J2.3, U4.7 (B)
RS485_0_RX: J3.4, U4.1 (RO)
RS485_0_TX: J3.10, U4.4 (DI)
RS485_0_TXE: J3.9, U4.2 (~RE), U4.3 (DE)
S0_0: C1.1, J2.2, J3.3, R1.1, R3.2
S0_1: C2.1, J2.1, J3.13, R2.1, R4.2
VCC: F1.2, J2.6
WMBus_ANT: J1.1 (In), U3.1 (ANT)
WMBus_URXD: J3.6, U3.5 (URXD)
WMBus_UTXD: J4.13, U3.4 (UTXD)
WMBus_~RTS: J4.12, U3.6 (~RTS)
WMBus_~Reset: U3.19 (~Reset)

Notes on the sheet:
WMBus/RS485
Connections
Bus Mapping
Power Supply


Board: 2 copper layers, 86.0 x 31.0 mm, 25 parts (1 on the bottom side), 18 nets.

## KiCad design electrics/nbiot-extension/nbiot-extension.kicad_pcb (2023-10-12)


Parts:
C1: 100nF; C_1206_3216Metric_Pad1.33x1.80mm_HandSolder
C2, C3, C4, C5: 33pF; C_1206_3216Metric_Pad1.33x1.80mm_HandSolder
C6, C7: 0F; C_0603_1608Metric_Pad1.08x0.95mm_HandSolder
J1: SIM_Card_Shielded; microSIM_JAE_SF53S006VCBR2000
J2: East; PinHeader_1x14_P2.54mm_Vertical
J3: West; PinHeader_1x14_P2.54mm_Vertical
J4: Conn_Coaxial; U.FL_Hirose_U.FL-R-SMT-1_Vertical
R1: 10k; R_1206_3216Metric_Pad1.30x1.75mm_HandSolder
R2, R3, R4: 22R; R_1206_3216Metric_Pad1.30x1.75mm_HandSolder
R5: 0R; R_0603_1608Metric_Pad0.98x0.95mm_HandSolder
U1: BC66NB-04-STD; XCVR_BC66NB-04-STD

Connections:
+3V3: J3.1
ANTENNA: C6.1, R5.1, U1.35 (RF_ANT); also elsewhere on the board
GND: C2.2, C3.2, C4.2, C5.2, C6.2, C7.2, J2.1, J4.2 (Ext), U1.1 (GND), U1.27 (GND), U1.34 (GND), U1.36 (GND), U1.37 (GND), U1.40 (GND), U1.41 (GND)
GNDPWR: J1.SH, J2.14
unnamed: C2.1, J1.7 (I/O), R4.2
unnamed: C3.1, J1.3 (CLK), R3.2
unnamed: C4.1, J1.2 (RST), R2.2
unnamed 7: C7.1, J4.1 (In), R5.2; also elsewhere on the board
unnamed: U1.2 (RESERVED), U1.3 (RESERVED), U1.4 (RESERVED), U1.5 (RESERVED), U1.6 (RESERVED), U1.8 (RESERVED), U1.21 (RESERVED), U1.22 (RESERVED), U1.23 (RESERVED), U1.25 (RESERVED), U1.26 (RESERVED), U1.30 (RESERVED), U1.31 (RESERVED), U1.32 (RESERVED), U1.33 (RESERVED), U1.44 (RESERVED), U1.45 (RESERVED), U1.46 (RESERVED), U1.48 (RESERVED), U1.52 (RESERVED), U1.53 (RESERVED), U1.54 (RESERVED), U1.55 (RESERVED), U1.56 (RESERVED), U1.57 (RESERVED), U1.58 (RESERVED)
SIM_CLK: R3.1, U1.13 (SIM_CLK)
SIM_DATA: R1.2, R4.1, U1.11 (SIM_DATA)
SIM_GND: C1.2, J1.5 (GND), U1.10 (SIM_GND)
SIM_RST: R2.1, U1.12 (SIM_RST)
SIM_VDD: C1.1, C5.1, J1.1 (VCC), R1.1, U1.14 (SIM_VDD)


Board: 2 copper layers, 56.0 x 30.4 mm, 18 parts (0 on the bottom side), 13 nets.

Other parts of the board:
L1: L; L_0805_2012Metric

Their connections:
ANTENNA: L1.1; also elsewhere on the board
unnamed 7: L1.2; also elsewhere on the board

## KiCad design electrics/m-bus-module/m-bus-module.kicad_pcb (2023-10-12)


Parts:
C1, C2, C3, C4: 100nF; C_1206_3216Metric_Pad1.33x1.80mm_HandSolder; mouser# 80-C1206C104M6R
C5: 100nF; C_0603_1608Metric_Pad1.08x0.95mm_HandSolder; mouser# 80-C1206C104M6R
D1: 25V; D_SOD-523; mouser# 750-CPDU24V
D2: 1N5819; D_SOD-323_HandSoldering; mouser# 771-PMEG4010CEAX
D3, D4: D_TVS; D_0603_1608Metric_Pad1.05x0.95mm_HandSolder; mouser# 652-CG0603MLC-3.3LE
F1: 25V/1A; Fuse_1206_3216Metric_Pad1.42x1.75mm_HandSolder; mouser# 504-TR/3216FF1-R
G1: Logo_Open_Hardware_Small; OSHW-Logo2_7.3x6mm_SilkScreen
G2: LOGO; grayc-logo-negative
J1: North; PHOENIX_1935200; mouser# 651-1935200
J2: South; PHOENIX_1935200; mouser# 651-1935200
J3: West; PinHeader_1x14_P2.54mm_Vertical; mouser# 855-M20-9991446
J4: East; PinHeader_1x14_P2.54mm_Vertical; mouser# 855-M20-9991446
R1, R2, R4: 10k; R_1206_3216Metric_Pad1.30x1.75mm_HandSolder; mouser# 652-CR1206JW-103ELF
R3, R5: 220R; R_1206_3216Metric_Pad1.30x1.75mm_HandSolder; mouser# 652-CR0603FX-2200ELF
U1: BA033CC0FP-E2; TO-252-3_TabPin2; mouser# 755-BA033CC0FP-E2
U2: MAX3486; SOIC-8_3.9x4.9mm_P1.27mm; mouser# 700-MAX3486EESA

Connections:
+3V3: C2.1, C5.1, J3.1, R2.2, R4.2, U1.3 (Output), U2.8 (VCC); also elsewhere on the board
GND: C1.2, C2.2, C3.2, C4.2, C5.2, D1.2 (A), D3.2 (A2), D4.2 (A2), J1.1, J1.3, J1.5, J4.1, J4.14, R1.2, U1.2 (GND), U2.5 (GND); also elsewhere on the board
M-Bus-1: J2.4; also elsewhere on the board
M-Bus-2: J2.3, J2.5; also elsewhere on the board
MBus_RX: J3.6; also elsewhere on the board
MBus_TX: J4.13; also elsewhere on the board
unnamed: C1.1, D2.1 (K), U1.1 (Input)
unnamed: D1.1 (K), D2.2 (A), F1.1, R1.1
unnamed: D3.1 (A1), R3.1
unnamed: D4.1 (A1), R5.1
RS485_A: J2.2, U2.6 (A)
RS485_B: J2.1, U2.7 (B)
RS485_RX: J3.4, U2.1 (RO)
RS485_TX: J3.10, U2.4 (DI)
RS485_TXE: J3.9, U2.2 (~RE), U2.3 (DE)
S0_0: C3.1, J1.4, J3.3, R2.1, R3.2
S0_1: C4.1, J1.2, J3.13, R4.1, R5.2
VBUS+: J2.6; also elsewhere on the board
VCC: F1.2, J1.6

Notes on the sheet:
Bus Mapping
RS485
Power Supply
Screw Terminal

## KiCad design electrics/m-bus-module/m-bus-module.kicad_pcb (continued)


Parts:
C6, C7, C8, C10: 0u1; C_0603_1608Metric_Pad1.08x0.95mm_HandSolder; mouser# 80-C1206C104M6R
C9: 47uF; CP_Elec_6.3x7.7; mouser# 80-EDK476M050S9HAA
D5, D6: BZT52C12-7-F; D_SOD-123; mouser# 621-BZT52C12-F
D7: BZT52C2V7-7-F; D_SOD-123; mouser# 621-BZT52C2V7-F
Q1: BC856B-13-F; SOT-23; mouser# 621-BC856B-13-F
Q2: BC846B-7-F; SOT-23; mouser# 621-BC846B-7-F
Q3: FDN5618P; SOT-23; mouser# 78-SI2309CDS-T1-BE3
R6, R7, R10, R14, R17: 10k; R_0603_1608Metric_Pad0.98x0.95mm_HandSolder; mouser# 660-RN73H1TD1002F25
R8, R15, R18, R20, R24: 100k; R_0603_1608Metric_Pad0.98x0.95mm_HandSolder; mouser# 660-RN73H1JTD1003F25
R9, R13, R19: 1k; R_0603_1608Metric_Pad0.98x0.95mm_HandSolder; mouser# 660-RN73H1JTD1001B25
R11, R12: 180k; R_0603_1608Metric_Pad0.98x0.95mm_HandSolder; mouser# 660-RN73H1JTD1803F25
R16: 4k7; R_0603_1608Metric_Pad0.98x0.95mm_HandSolder; mouser# 660-RN73H1JT4701F100
R21, R22, R25: 20k; R_0603_1608Metric_Pad0.98x0.95mm_HandSolder; mouser# 660-RN73H1JTD2002B10
R23: 100R; R_0603_1608Metric_Pad0.98x0.95mm_HandSolder; mouser# 660-RN73H1JTD1000F50
U3, U4: VOM452T; SOIC127P700X230-5N; mouser# 782-VOM452T
U5: MC33072ADR2G; SOIC127P600X175-8N; mouser# 511-LM258ADT
U6: LM4040DIM3-5.0/NOPB; SOT-23; mouser# 926-LM4040DIM350NOPB

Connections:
+3V3: C6.1, Q1.2 (E), R6.2, R8.2, U4.6; also elsewhere on the board
GND: U3.3; also elsewhere on the board
M-Bus-1: R22.1, R23.1, R24.1; also elsewhere on the board
M-Bus-2: C6.2, C7.2, C8.2, C9.2, C10.2, D5.2 (A), Q2.2 (E), R12.2, R20.1, R24.2, U3.4, U4.3, U4.4, U5.4 (V-), U6.2 (A); also elsewhere on the board
MBus_RX: R7.1; also elsewhere on the board
MBus_TX: R6.1, U4.5; also elsewhere on the board
unnamed: C7.1, D5.1 (K), R14.1, R15.2, U3.6
unnamed: C8.1, R19.2, R25.1, U6.1 (K)
unnamed: D6.2 (A), D7.1 (K), Q3.3 (D)
unnamed: D7.2 (A), R21.1, R23.2
unnamed: Q1.1 (B), R7.2, R8.1
unnamed: Q1.3 (C), R9.1
unnamed: Q2.1 (B), R15.1, U3.5
unnamed: Q2.3 (C), R17.1
unnamed: Q3.1 (G), R16.1, R17.2
unnamed: R9.2, U3.1
unnamed: R10.1, U4.1
unnamed: R10.2, R11.2, U5.7
unnamed: R11.1, R13.2, U5.5 (+)
unnamed: R12.1, R19.1, U5.6 (-)
unnamed: R13.1, R18.2, U5.1
unnamed: R18.1, R22.2, U5.2 (-)
unnamed: R20.2, R21.2, U5.3 (+)
VBUS+: C9.1, C10.1, D6.1 (K), Q3.2 (S), R14.2, R16.2, R25.2, U5.8 (V+); also elsewhere on the board


Board: 2 copper layers, 86.0 x 31.0 mm, 58 parts (1 on the bottom side), 36 nets.

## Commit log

2021-11-09 Initial Project Structure
    [ethernet-extension.kicad_pcb, ethernet-extension.sch, soc-module.kicad_pcb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]
2021-11-09 SoC Module Work On
    [soc-module.kicad_pcb, soc-module.sch]
2021-11-24 Ongoing Work Metering Module
    [metering-module.kicad_pcb, metering-module.sch, soc-module.kicad_pcb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]
2021-11-26 Consolidate subfolders
    [ethernet-extension.kicad_pcb, ethernet-extension.sch, metering-module.kicad_pcb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]
2021-12-15 Ongoing Work
    [ethernet-extension.kicad_pcb, ethernet-extension.sch, metering-module.kicad_pcb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]
2022-01-20 Ongoing Work. Still not ready for small and dedicated commits.
    [IO_Interface.sch, PC_Interface.sch, USB_Interface.sch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]
2022-02-01 Use a cheaper SD card interface
    [soc-module.kicad_pcb, soc-module.sch]
2022-02-01 Use a GPIO expander for metering module to safe pins
    [metering-module.kicad_pcb, metering-module.sch]
2022-02-09 Introduce new serial numbering scheme
    [development-board.kicad_pcb, metering-module.kicad_pcb, metering-module.sch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]
2022-02-09 Added pin out section to documentation
2022-03-04 Work on Ethernet module
    [ethernet-extension.kicad_pcb, ethernet-extension.sch, metering-module.kicad_pcb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]
2022-03-04 Fix build
    [ethernet-extension.kicad_pcb]
2022-03-04 Added panel module to CI build
    [ethernet-extension.kicad_pcb, panel-module.kicad_pcb]
2022-03-08 Added Panel Module to build
    [ethernet-extension.kicad_pcb, ethernet-extension.sch, panel-module.sch]
2022-03-10 Added metering module to CI build
    [metering-module.kicad_pcb, metering-module.sch]
2022-03-18 Better Silk placings for Panel Module
    [panel-module.kicad_pcb]
2022-03-18 Preparation of LoRa Metering Module
    [lora-module.kicad_pcb, lora-module.sch]
2022-03-18 NB IoT ongoing work
    [nbiot-extension.kicad_pcb, nbiot-extension.sch]
2022-03-22 Added SMA connector for LoRa module
    [lora-module.kicad_pcb, lora-module.sch]
2022-03-29 Ongoing work LoRa module
    [lora-module.kicad_pcb, lora-module.sch]
2022-07-05 Added OpenHardware Logo to PCBs
    [ethernet-extension.kicad_pcb, ethernet-extension.sch, lora-module.kicad_pcb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]
2022-07-05 Fix Footprint of MCP23009
    [metering-module.kicad_pcb, metering-module.sch]
2022-07-20 Fix too low net clearance
    [metering-module.kicad_pcb, metering-module.sch, probe-module.kicad_pcb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]
2023-01-17 Feature/kicad 6 migration (#1)
    * Adjust CI/CD jobs to use KiCad 6
    * Migrate panel module project
    * Unify KiBot config
    * Migrate Ethernet, SoC, Metering Modules to KiCad6
    * Change build order to find out more about strange behavior
    * Trigger build also on workflow changes
    * Try to increase log level to track error
    * Switch to KiCad 6 schematic files
    * Fix / Ignore Errors in panel module
    * Disable cost calculation for now
    * Fixing more ERC errors
    * Remove outdated files and settings
    * Trim further warnings and errors
    * Update documentation
    [ethernet-extension.kicad_pcb, ethernet-extension.kicad_sch, ethernet-extension.sch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]
2023-01-19 Feature/kicad 6 migration (#2)
    * Migrate in-progress projects
    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
    [IO_Interface.kicad_sch, IO_Interface.sch, PC_Interface.kicad_sch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]
2023-02-13 Feature/kicad 6 migration (#3)
    * Restructured project to get common builds and documentation
    * Fix main job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
    [IO_Interface.kicad_sch, PC_Interface.kicad_sch, USB_Interface.kicad_sch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]
2023-02-13 Feature/kicad 6 migration (#4)
    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
2023-02-15 Feature/kicad 6 migration (#5)
    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
2023-02-17 Feature/kicad 6 migration (#6)
    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
2023-03-06 Feature/kicad 6 migration (#7)
    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
2023-03-10 Feature/kicad 6 migration (#8)
    * Added proper PCB pictures to build output
    * Added product numbers for cost calculation
    * Reactivate KiCost
    [ethernet-extension.kicad_sch, metering-module.kicad_pcb, metering-module.kicad_sch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]
2023-03-17 Feature/dedicated mieterstrom module (#9)
    * Remove outdated files to clean things up
    * Added missing part numbers for metering module
    * Added 6 position screw terminal
    * Added "mieterstrom" module
    * Throw generated XML files out of version control
    * Add "mieterstrom" module to local build
    * Add "Mieterstrom" module to documentation
    * Added "Mieterstrom" module to CI/CD
    [USB_Interface.kicad_sch, debug-module.kicad_pcb, debug-module.kicad_sch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]
2023-04-03 Feature/rtc for soc module (#10)
    * Added optional RTC to SoC module
    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
    [soc-module.kicad_pcb, soc-module.kicad_sch]
2023-10-12 M bus module (#12)
    * Fix wrong resistor manufacturer number in panel module
    * Added missing labels for bus connectors in "Mieterstrom" module
    * Added missing 3D model for BC66NB
    * Finalized PoC for M-Bus module
    * Updated documentation
    [m-bus-module.kicad_pcb, m-bus-module.kicad_sch, m-bus.kicad_sch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]
2024-11-28 Add CT metering module (#14)
    * Add CT metering module
    * Review Fixes
    * Fix missing 3D image
    ---------
    [ct-module.kicad_pcb, ct-module.kicad_sch]
2025-01-07 INOA-372 EMS, Debug, Development module (#15)
    * INOA-372 Finalize CT module
    * INOA-372 Fix out of stock components in SoC module
    * INOA-372 Fix out of stock components in TM module
    * INOA-372 Rename Fab and Dev board
    * INOA-372 Fix autoprogrammer for debug module
    * INOA-372 Fix schematic annotations for MBus module
    * INOA-372 Enhance documentation
    * INOA-372 Add new modules to build pipeline
    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
    [IO_Interface.kicad_sch, PC_Interface.kicad_sch, USB_Interface.kicad_sch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]
